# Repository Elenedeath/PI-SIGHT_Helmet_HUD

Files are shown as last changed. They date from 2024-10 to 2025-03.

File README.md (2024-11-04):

# PI-SIGHT Helmet HUD

PI-SIGHT Helmet HUD는 헬멧 외부에 장착하여 사용자의 눈앞에 필요한 정보를 표시하는 헤드 업 디스플레이 장치 입니다. 사용자는 고개를 움직이지 않고도 눈앞의 디스플레이를 통해 필요한 정보 또는 후방카메라 영상을 확인할 수 있습니다.

기기의 가장 큰 특징은 소형 범용 컴퓨터인 라즈베리 파이와 교체식 모듈 시스템을 적용했다는 것입니다. 이를 통해 사용자가 직접 소프트웨어를 프로그래밍하거나 필요한 소프트웨어로 교체할 수 있고, 블루투스 헤드셋이나 GPS 모듈을 연결해 내비게이션, 레이싱 계측기, 항공 계기판 등 다양한 용도로 사용할 수 있습니다.

## 기능

 - 프리즘 디스플레이 : 눈앞에 위치한 3000cd/m^2 디스플레이를 통해 고개를 움직이거나 별도의 기기를 거치하지 않아도 필요한 정보를 확인할 수 있음
 - 범용 시스템 : 범용 리눅스 컴퓨터인 라즈베리파이를 사용해 목적에 맞는 프로그램과 센서를 쉽게 개발하여 적용할 수 있음
 - 교체형 모듈 시스템 : 프로그램과 모듈을 쉽게 교체할 수 있도록 하여 한 대의 기기를 다양한 활동에서 사용할 수 있음
 - 무선 리모컨, 후방 카메라 등 자세한 내용은 [VUDEV 웹사이트](https://sites.google.com/vudev.net/vudevnet/about-pi-sight) 또는 [설명서](https://github.com/younsj97/PI-SIGHT_Helmet_HUD/blob/main/PI-SIGHT%20%EC%82%AC%EC%9A%A9%EC%84%A4%EB%AA%85%EC%84%9C-1%20(%EB%94%94%EB%B0%94%EC%9D%B4%EC%8A%A4%20%EA%B8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)를 다운로드하여 확인하세요

## 소프트웨어

 1. [Openauto](https://github.com/younsj97/PI-SIGHT_SW_Openauto) : 안드로이드 스마트폰과 연결해 안드로이드 오토 헤드 유닛으로 사용할 수 있습니다.
 2. [GPS Racer](https://github.com/younsj97/PI-SIGHT_SW_GPSRacer) : 자체 랩타이머 또는 스마트폰 연동 블루투스 GPS 수신기로 사용할 수 있습니다.
 3. [Rearview](https://github.com/younsj97/PI-SIGHT_SW_Rearview) : 실시간 후방 카메라 영상을 보여주며, 작동 중 자동으로 녹화됩니다.
 - 누구든지 필요한 프로그램과 모듈을 제작해 사용할 수 있습니다.

## 제작 방법

 - 업로드 예정

## 주의사항

 - _PI-SIGHT는 다양한 환경에서 충분한 테스트를 거치지 않았습니다. 제작과 사용은 자유지만, 그로 인해 발생하는 문제에 대하여 책임지지 않습니다._
 - _PI-SIGHT는 방진,방수를 지원하지 않습니다. 물이 들어가지 않도록 하세요_
 - _프리즘 디스플레이의 텐션 조절 볼트가 너무 느슨하면 사용 중 디스플레이가 움직여 위험할 수 있습니다_

## 커스터마이징

 - 무선 리모컨 펌웨어는 [PI-SIGHT Remote Controller SW](https://github.com/younsj97/PI-SIGHT_SW_RemoteController)를 참고하세요
 - PCB 회로 및 모듈 커넥터는 [회로](https://github.com/younsj97/PI-SIGHT_Helmet_HUD/blob/main/Documents/Circuits.pdf) 자료를 참고하세요

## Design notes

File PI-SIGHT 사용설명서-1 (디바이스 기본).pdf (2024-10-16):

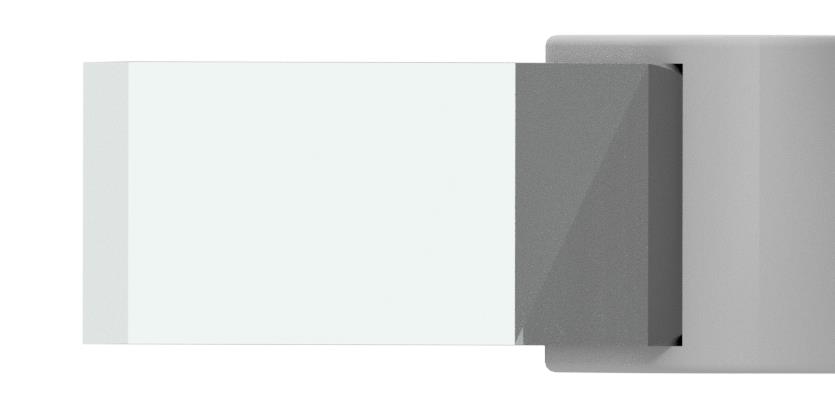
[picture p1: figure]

# PI-SIGHT 기기 사용 설명서

www.vudev.net | VUDEV | PI-SIGHT

주의사항 · · · · · · · · · · · · · · · · · · · · · · · · · · · · · · · · · · · · · · · · · · · · · · · · · · · · · · · · · · · · · · 3 1 소개/제품 구성 · · · · · · · · · · · · · · · · · · · · · · · · · · · · · · · · · · · · · · · · · · · · · · · · · · · · · · · 4 2 기술 사양 · · · · · · · · · · · · · · · · · · · · · · · · · · · · · · · · · · · · · · · · · · · · · · · · · · · · · · · · · · 5

### 3 시작하기

3.1 PI-SIGHT 부품명 · · · · · · · · · · · · · · · · · · · · · · · · · · · · · · · · · · · · · · · · · · · · · · 6 3.2 바디 세트 설치하기 · · · · · · · · · · · · · · · · · · · · · · · · · · · · · · · · · · · · · · · · · · · · · 8 3.3 리모컨 설치하기 · · · · · · · · · · · · · · · · · · · · · · · · · · · · · · · · · · · · · · · · · · · · · · · 11 3.4 배터리 및 메모리카드 넣기 · · · · · · · · · · · · · · · · · · · · · · · · · · · · · · · · · · · · · · · 12 3.5 전원 켜기 및 끄기, 충전하기 · · · · · · · · · · · · · · · · · · · · · · · · · · · · · · · · · · · · · · 13 4 소프트웨어 설치 · · · · · · · · · · · · · · · · · · · · · · · · · · · · · · · · · · · · · · · · · · · · · · · · · · · · · 19 5 문제 해결 · · · · · · · · · · · · · · · · · · · · · · · · · · · · · · · · · · · · · · · · · · · · · · · · · · · · · · · · · · 20 5.1 메인바디 작동 문제
5.2 리모컨 충전 불빛 문제
5.3 디스플레이 고정 문제
목차 | VUDEV | PI-SIGHT

다음 주의사항을 준수하십시오.

- 카메라 사용과 관련된 모든 규정을 준수하십시오.
- 카메라는 낮은 수준의 자기장이 발생합니다. 간섭을 피하기 위해 의료장비와 거리를 유지하 십시오.
- 카메라에서 발생하는 낮은 수준의 자기장은 다른 전자기기에 간섭을 일으킬 수 있습니다.
- 부주의하게 사용하면 위험하며 심각한 상해를 초래할 수 있습니다. 문서의 안전을 위한 주의 사항을 준수해야 합니다.
- 무선통신이 금지된 장소에서는 제품의 전원을 끄십시오.
- 사용 전에 제품이 올바르게 고정되었는지 다시 한번 확인하십시오. 사용 중 제품이 분리될 경 우 제품이 손상되고 사고가 발생할 수 있습니다
- 제품을 사용하거나 충전하는 중에 비정상적인 냄새가 나거나 발열 또는 다른 이상 증상이 보 인다면 즉시 충전이나 사용을 멈추십시오.
- 제품을 헬멧에 장착하는 경우 헬멧의 보증이 무효가 되거나 헬멧의 기능을 방해할 수 있습니 다. 따라서 제품을 사용하시기 전에 이로 인해 초래되는 사고 발생 시의 위험에 대해서 충분히 숙지해야 합니다.
- 제품을 사용하기 전에 해당 지역의 법률을 이해하고 해당 규정을 준수하는지 확인하십시오.
- 날카로운 공구로 제품에 충격을 가하거나, 케이블을 과도하게 잡아당기지 마십시오. 제품이 손상될 수 있습니다.
주의사항 | VUDEV | PI-SIGHT
- 애완동물이나 유아의 손이 닿지 않는 곳에 보관하십시오.
- 카메라가 정상적으로 작동하는지 사전에 확인하십시오.
- 직사광선 아래에서 장시간 사용하지 마십시오. 제품이 손상되고 발열로 화상을 입을 수 있습 니다.
- 더운 날씨에 자동차 내부에서 배터리를 장착한 제품을 사용하거나 보관하지 마십시오. 배터 리가 발열 또는 발화할 수 있습니다.
- 물리적으로 손상된 배터리를 장착하지 마십시오. 폭발이나 사고의 원인이 될 수 있습니다.
- 배터리 수명은 상황, 환경, 기능에 따라 달라질 수 있습니다.
- 제품을 상온에 보관하십시오. 극단적인 저온이나 고온에 둘 경우 기기가 손상될 수 있습니다.
- 디스플레이 보호에 유의하고, 프리즘에 이물질이 붙었을 경우 부드러운 천으로 표면을 닦으 십시오.
- 제품에 방수 기능이 없기 때문에 비나 눈이 오는 환경에서 제품을 사용하지 마십시오.
- 이 기기는 업무용(A급) 전자파적합기기로서 판매자 또는 사용자는 이 점을 주의하시기 바라 며, 가정외의 지역에서 사용하는 것을 목적으로 합니다.

PI-SIGHT를 구매해 주셔서 감사합니다.

PI-SIGHT는 헬멧 착용자의 눈앞에 필요한 정보를 표시하는 헤드 업 디스플레이(HUD) 장치 입 니다.
여러분은 눈앞의 반투명 디스플레이를 통해 고개를 움직이지 않고 필요한 정보를 확인할 수 있 고, 무선 리모컨을 통해 기기를 조작할 수 있습니다.

라즈베리 파이 제로 2W 보드와 라즈베리 파이 OS를 기반으로 작동하며, 메모리카드에 원하는 소프트웨어를 다운받아 설치하거나 직접 개발하여 사용할 수 있습니다.
또한 블루투스 헤드셋이나 GPS와 같은 외장 모듈을 연결할 수 있으므로, 필요에 따라 내비게이 션, 레이싱 계측기, 항공 계기판 등 다양한 용도로 사용할 수 있습니다.

본 설명서에서는 기본적으로 제공되는 리어뷰 소프트웨어에 대한 내용을 다룹니다. 기기에서 녹 화한 영상을 확인하기 위해서는 별도의 윈도우 PC가 필요합니다.

PI-SIGHT에 사용할 수 있는 모듈과 소프트웨어에 대한 더 많은 정보는 vudev.net 을 참고하 십시오.

1. 소개 / 제품 구성 | VUDEV | PI-SIGHT

상자에는 다음과 같은 항목이 있습니다.

- PI-SIGHT 디스플레이 유닛
- PI-SIGHT 메인바디-카메라 유닛
- PI-SIGHT 파이 마이크 유닛
- PI-SIGHT 리모컨
- 마이크로 SD 메모리 (리어뷰 소프트웨어 설치)
- 헬멧 마운트
- 마이크 부착용 벨크로
- 십자 드라이버
- 사용 설명서
*제품에는 배터리와 충전기가 포함되어 있지 않습니다. 제품을 작동시키고 충전하려면 별도로 구입해야 합니다. 자세한 내용은 기술 사양을 참조하십시오.
*제품에는 마이크로 SD 메모리를 PC에 연결할 수 있는 어댑터가 포함되어 있지 않습니다. 녹화 영상을 확인하고 소프트웨어 재설치를 위해서는 별도로 구입해야 합니다.

PI-SIGHT 바디 세트

- 길이: 메인바디 105.5mm / 카메라 21mm / 디스플레이 71mm
- 높이: 메인바디 35mm / 카메라 23.5mm / 디스플레이 47.5mm
- 너비: 메인바디 34.4mm / 카메라 35mm / 디스플레이 38mm
- 무게: 145g (배터리 포함)
- 화면 크기: 0.23인치 / 3미터 50인치
- 화면 해상도: 640*400
- 카메라: 500만 화소 120도 광각
- 비디오 해상도: 1296*860p (사용자가 변경 가능 / 최대 1920*1080p)
- 메인보드: 라즈베리파이 제로 2W
- 프로세서: 1GHz quad-core 64-bit Arm Cortex-A53 CPU
- 램 용량: 512MB
- 무선 통신: 2.4GHz 802.11 b/g/n Wi Fi , Bluetooth 4.2, BLE
- 커넥터: 충전용 USB-C, 디스플레이용 3.5mm, 파이 마이크용 3.5mm
- 메모리카드: 32GB 마이크로 SD (추가 구입 시 Class 10 이상 권장)
- *배터리: 18650 리튬이온 교체식
*배터리 별도 구입 필요
2. 기술 사양 | VUDEV | PI-SIGHT

PI-SIGHT 리모컨

- 길이: 87mm
- 높이: 87.5mm
- 너비: 23mm
- 무게: 85g (배터리 포함)
- 커넥터: 충전용 USB-C
- 무선 통신: Bluetooth 4.2
- *배터리: 18650 리튬이온 교체식
*배터리 별도 구입 필요
- 작동 시간: 메인바디 약 5시간, 리모컨 약 16시간 (3500mAh, 화면 밝기 중간 기준, 사용 소프트웨어마다 다를 수 있음)

## 3. 시작하기

– PI

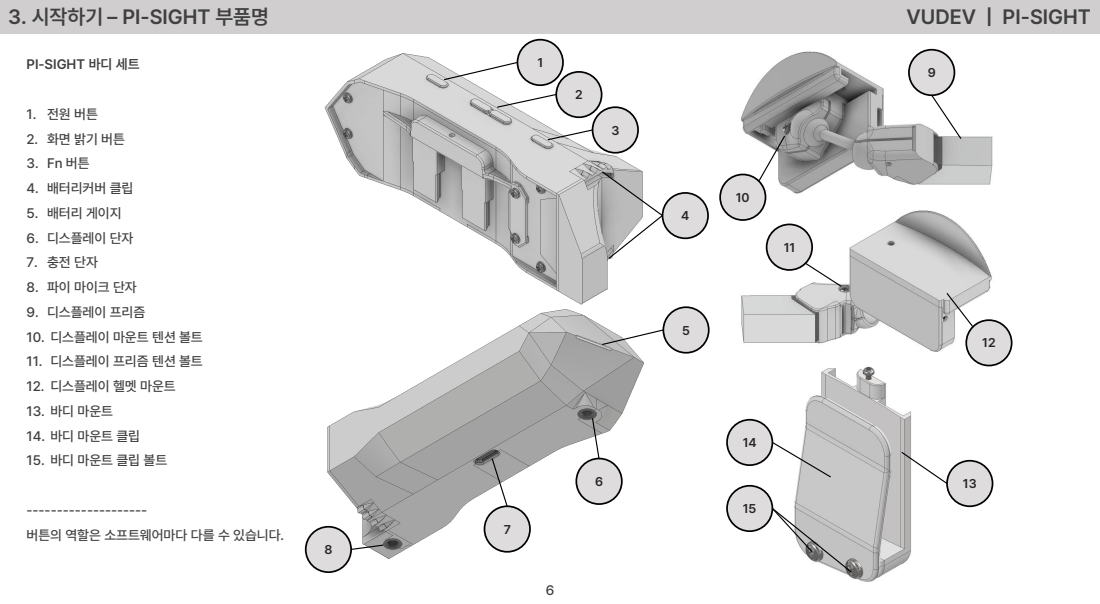
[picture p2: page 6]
수 있습니다; -SIGHT 부품명; VUDEV | PI; -SIGHT

-SIGHT 바디 세트

4. 배터리커버 클립
5. 배터리 게이지
6. 디스플레이 단자
8. 파이 마이크 단자
9. 디스플레이 프리즘
10. 디스플레이 마운트 텐션 볼트
11. 디스플레이 프리즘 텐션 볼트
12. 디스플레이 헬멧 마운트
13. 바디 마운트
14. 바디 마운트 클립
15. 바디 마운트 클립 볼트

버튼의 역할은 소프트웨어마다 다를

3. 시작하기 – PI-SIGHT 부품명 | VUDEV | PI-SIGHT

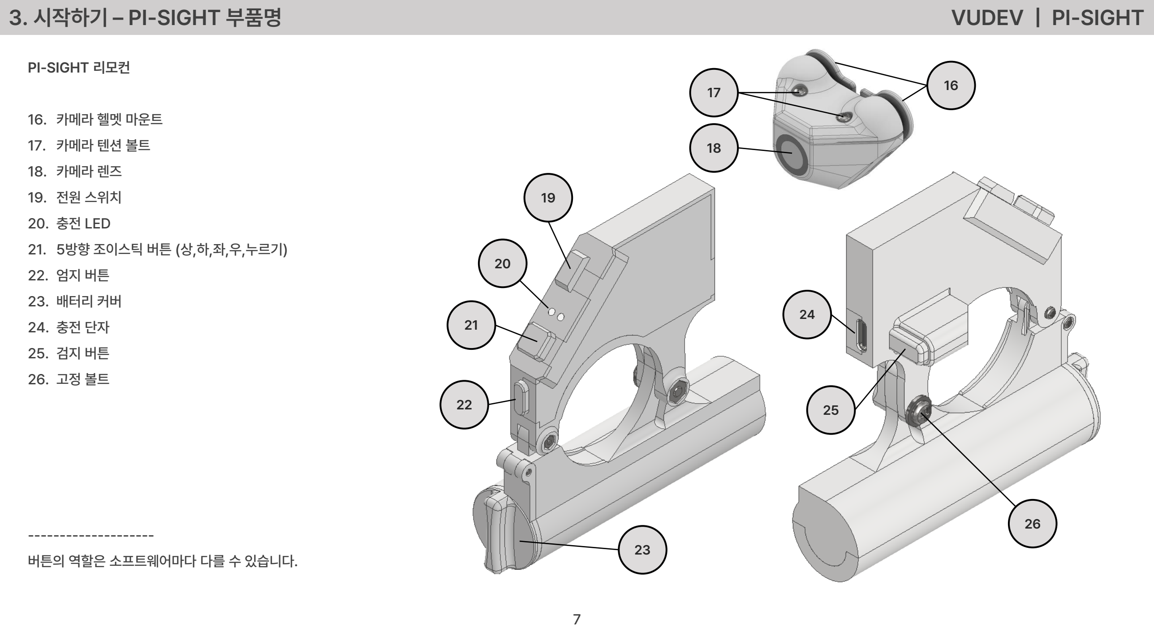
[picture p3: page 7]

PI-SIGHT 리모컨

16. 카메라 헬멧 마운트
17. 카메라 텐션 볼트
18. 카메라 렌즈
19. 전원 스위치
20. 충전 LED
21. 5방향 조이스틱 버튼 (상,하,좌,우,누르기)
22. 엄지 버튼
23. 배터리 커버
24. 충전 단자
25. 검지 버튼
26. 고정 볼트
버튼의 역할은 소프트웨어마다 다를 수 있습니다.

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
16 17

18

3. 시작하기 – 바디 세트 설치하기 | VUDEV | PI-SIGHT

1 2

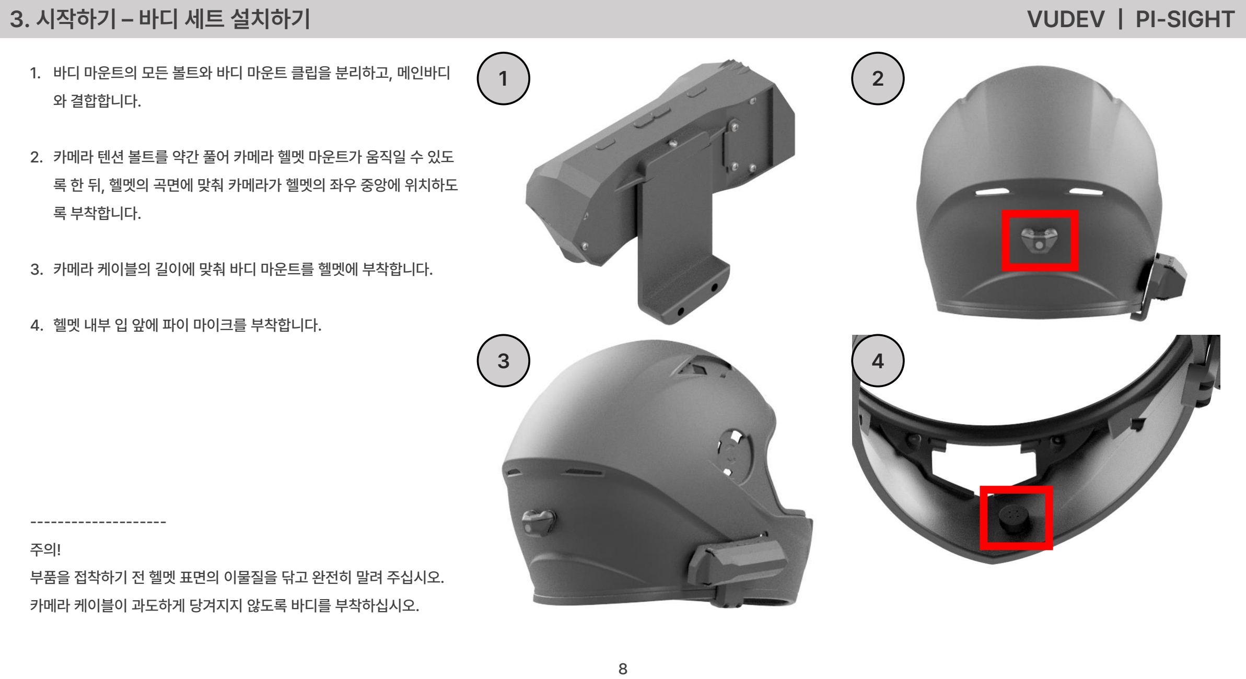
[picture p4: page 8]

1. 바디 마운트의 모든 볼트와 바디 마운트 클립을 분리하고, 메인바디 와 결합합니다.
2. 카메라 텐션 볼트를 약간 풀어 카메라 헬멧 마운트가 움직일 수 있도 록 한 뒤, 헬멧의 곡면에 맞춰 카메라가 헬멧의 좌우 중앙에 위치하도 록 부착합니다.
3. 카메라 케이블의 길이에 맞춰 바디 마운트를 헬멧에 부착합니다.
4. 헬멧 내부 입 앞에 파이 마이크를 부착합니다.
주의!
부품을 접착하기 전 헬멧 표면의 이물질을 닦고 완전히 말려 주십시오. 카메라 케이블이 과도하게 당겨지지 않도록 바디를 부착하십시오.

3 4

3. 시작하기 – 바디 세트 설치하기 | VUDEV | PI-SIGHT

5 6

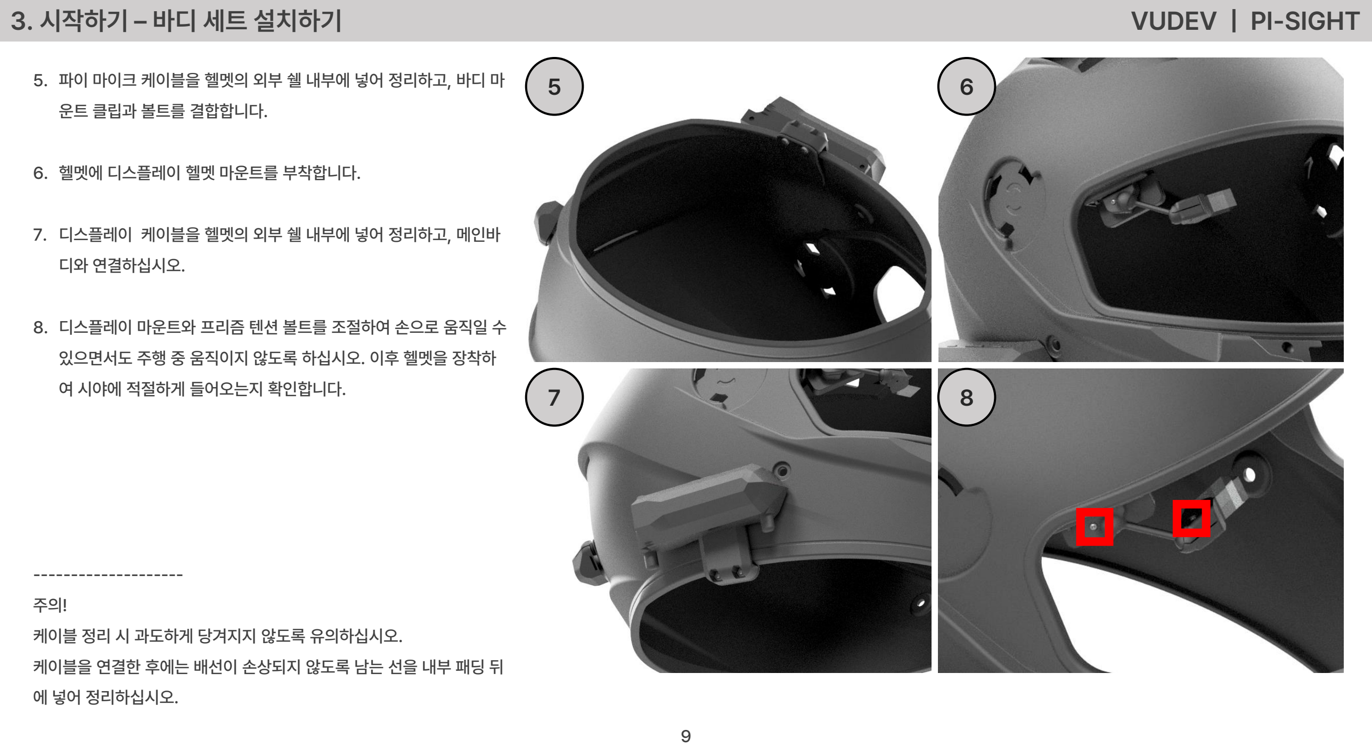
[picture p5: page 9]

7 8

5. 파이 마이크 케이블을 헬멧의 외부 쉘 내부에 넣어 정리하고, 바디 마 운트 클립과 볼트를 결합합니다.
6. 헬멧에 디스플레이 헬멧 마운트를 부착합니다.
7. 디스플레이 케이블을 헬멧의 외부 쉘 내부에 넣어 정리하고, 메인바 디와 연결하십시오.
8. 디스플레이 마운트와 프리즘 텐션 볼트를 조절하여 손으로 움직일 수 있으면서도 주행 중 움직이지 않도록 하십시오. 이후 헬멧을 장착하 여 시야에 적절하게 들어오는지 확인합니다.
주의!
케이블 정리 시 과도하게 당겨지지 않도록 유의하십시오.
케이블을 연결한 후에는 배선이 손상되지 않도록 남는 선을 내부 패딩 뒤 에 넣어 정리하십시오.

3. 시작하기 – 바디 세트 설치하기 | VUDEV | PI-SIGHT

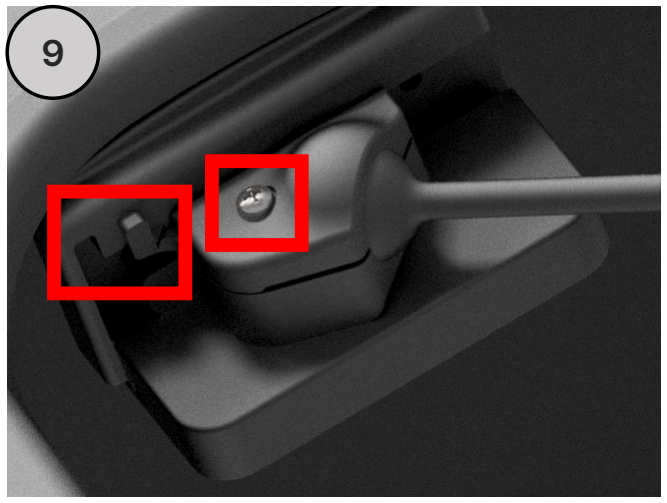
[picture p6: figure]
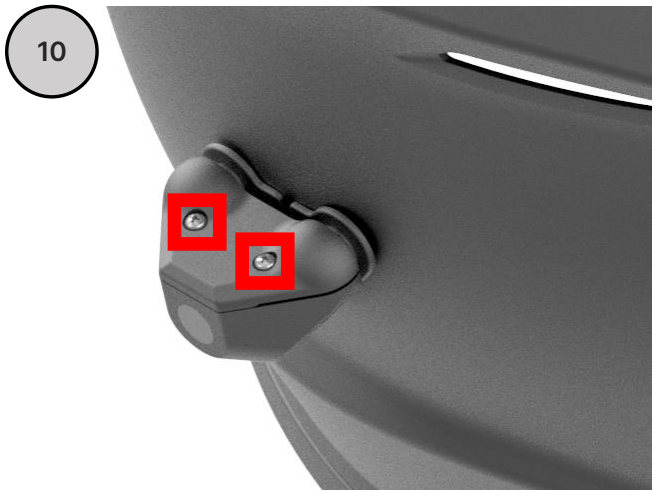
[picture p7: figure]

9 10 9. 디스플레이 마운트 텐션 볼트를 완전히 풀고 커버를 분리하면 클립을
움직여 마운트를 앞뒤로 1단계 조절할 수 있습니다.
10. 전원을 켜고 후방카메라를 확인해 카메라의 상하 각도를 조절하고,
카메라 텐션 볼트를 조여 움직이지 않도록 하십시오.

3. 시작하기 – 리모컨 설치하기 | VUDEV | PI-SIGHT

1 2

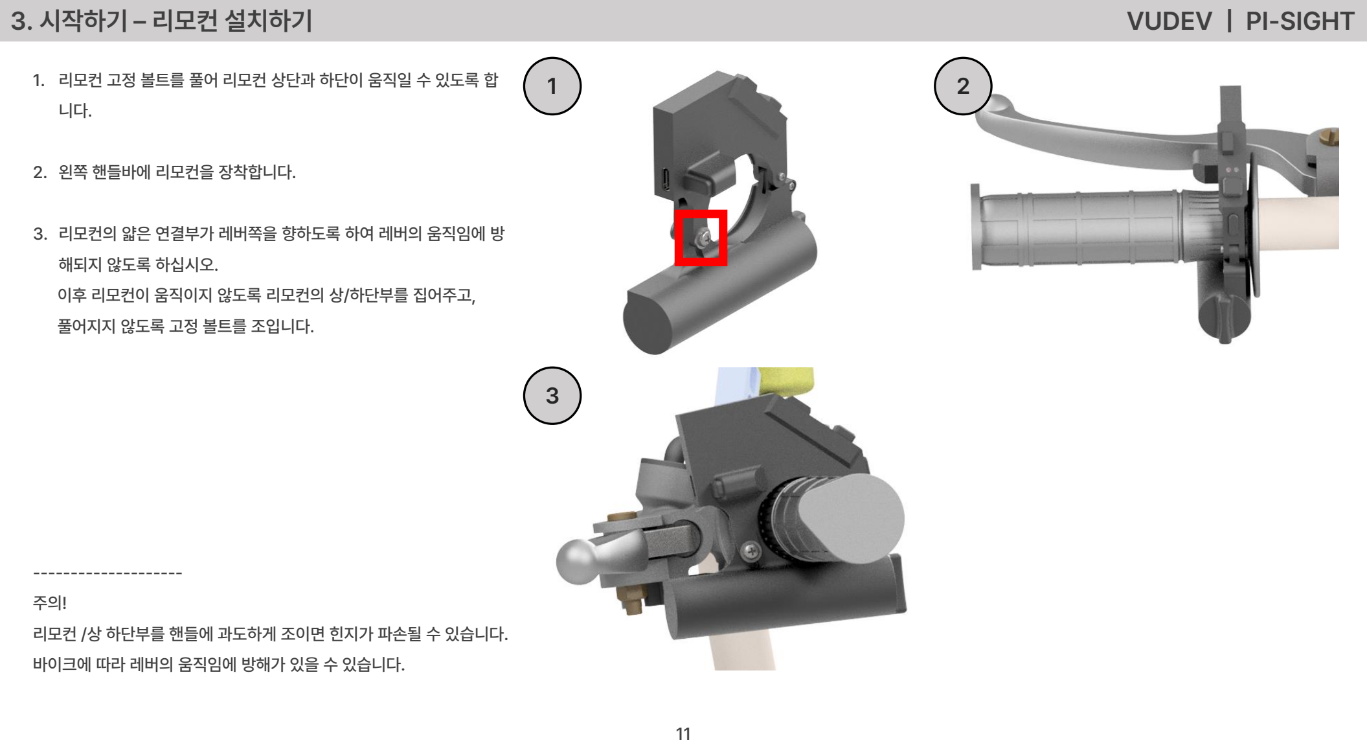
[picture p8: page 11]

3

1. 리모컨 고정 볼트를 풀어 리모컨 상단과 하단이 움직일 수 있도록 합 니다.
2. 왼쪽 핸들바에 리모컨을 장착합니다.
3. 리모컨의 얇은 연결부가 레버쪽을 향하도록 하여 레버의 움직임에 방 해되지 않도록 하십시오.
이후 리모컨이 움직이지 않도록 리모컨의 상/하단부를 집어주고, 풀어지지 않도록 고정 볼트를 조입니다.
주의!
리모컨 /상 하단부를 핸들에 과도하게 조이면 힌지가 파손될 수 있습니다. 바이크에 따라 레버의 움직임에 방해가 있을 수 있습니다.

3. 시작하기 – 배터리 및 메모리카드 넣기 | VUDEV | PI-SIGHT

1 2

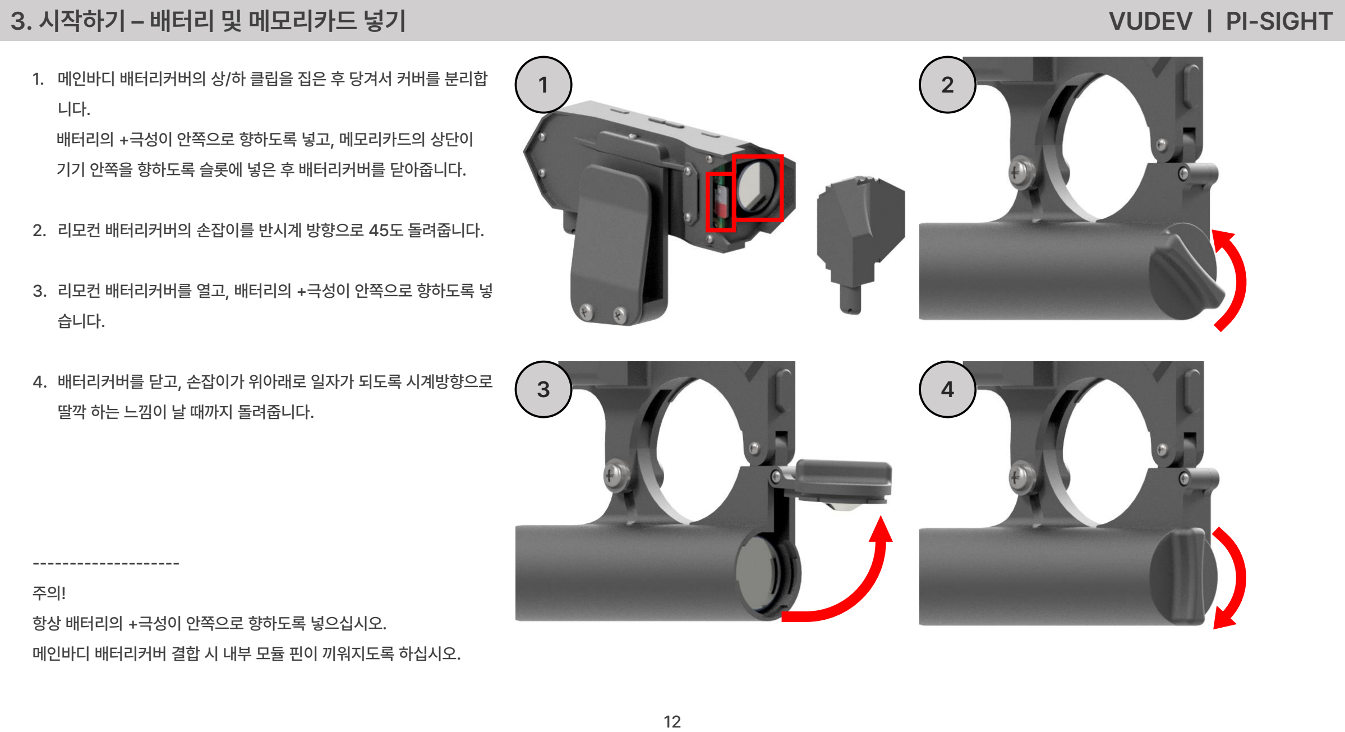
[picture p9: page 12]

3 4

1. 메인바디 배터리커버의 상/하 클립을 집은 후 당겨서 커버를 분리합 니다.
배터리의 +극성이 안쪽으로 향하도록 넣고, 메모리카드의 상단이 기기 안쪽을 향하도록 슬롯에 넣은 후 배터리커버를 닫아줍니다.
2. 리모컨 배터리커버의 손잡이를 반시계 방향으로 45도 돌려줍니다.
3. 리모컨 배터리커버를 열고, 배터리의 +극성이 안쪽으로 향하도록 넣 습니다.
4. 배터리커버를 닫고, 손잡이가 위아래로 일자가 되도록 시계방향으로 딸깍 하는 느낌이 날 때까지 돌려줍니다.
주의!
항상 배터리의 +극성이 안쪽으로 향하도록 넣으십시오.
메인바디 배터리커버 결합 시 내부 모듈 핀이 끼워지도록 하십시오.

3. 시작하기 – 전원 켜기 및 끄기,충전하기 | VUDEV | PI-SIGHT

1 2

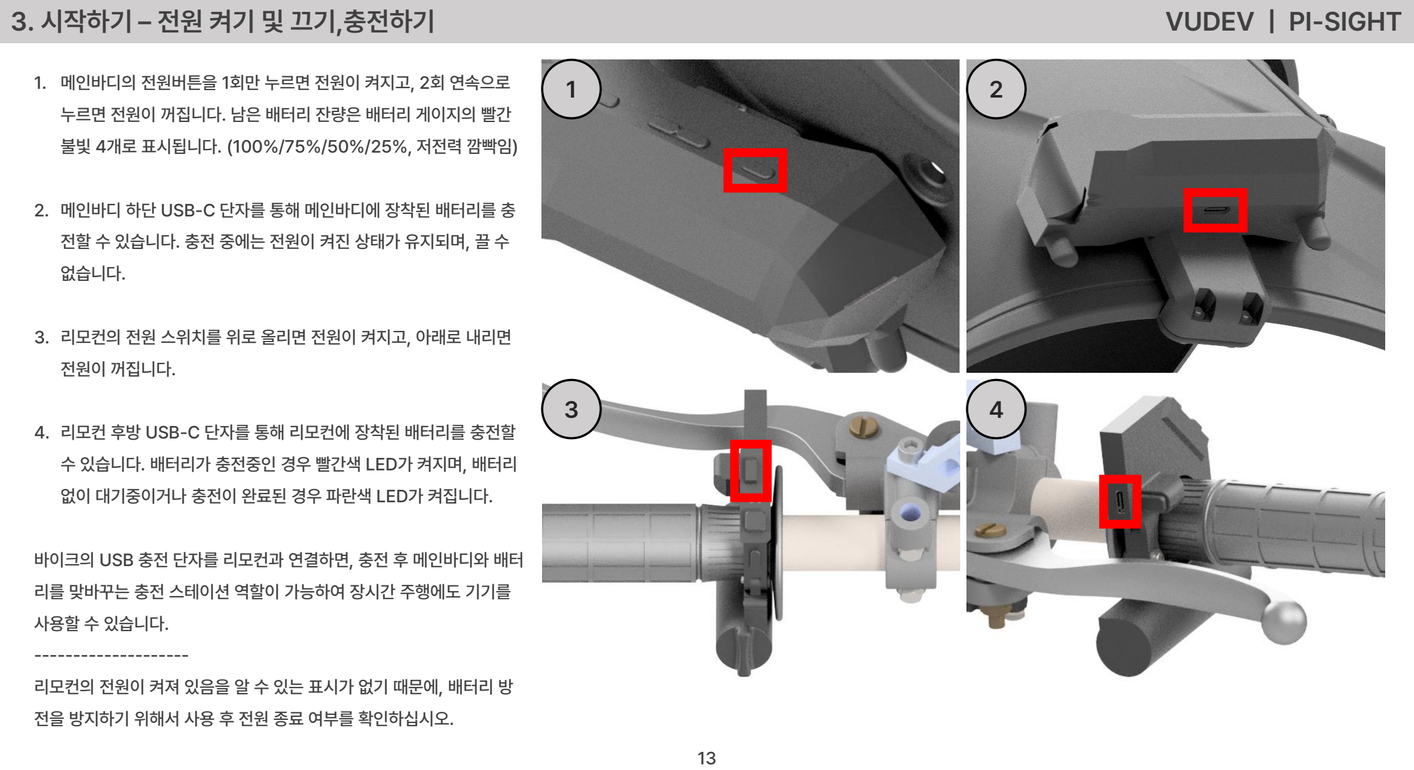
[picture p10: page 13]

3 4

1. 메인바디의 전원버튼을 1회만 누르면 전원이 켜지고, 2회 연속으로 누르면 전원이 꺼집니다. 남은 배터리 잔량은 배터리 게이지의 빨간 불빛 4개로 표시됩니다. (100%/75%/50%/25%, 저전력 깜빡임)
2. 메인바디 하단 USB-C 단자를 통해 메인바디에 장착된 배터리를 충 전할 수 있습니다. 충전 중에는 전원이 켜진 상태가 유지되며, 끌 수 없습니다.
3. 리모컨의 전원 스위치를 위로 올리면 전원이 켜지고, 아래로 내리면 전원이 꺼집니다.
4. 리모컨 후방 USB-C 단자를 통해 리모컨에 장착된 배터리를 충전할 수 있습니다. 배터리가 충전중인 경우 빨간색 LED가 켜지며, 배터리 없이 대기중이거나 충전이 완료된 경우 파란색 LED가 켜집니다.

바이크의 USB 충전 단자를 리모컨과 연결하면, 충전 후 메인바디와 배터 리를 맞바꾸는 충전 스테이션 역할이 가능하여 장시간 주행에도 기기를 사용할 수 있습니다.
리모컨의 전원이 켜져 있음을 알 수 있는 표시가 없기 때문에, 배터리 방 전을 방지하기 위해서 사용 후 전원 종료 여부를 확인하십시오.

4. 소프트웨어 설치 | VUDEV | PI-SIGHT

1 2

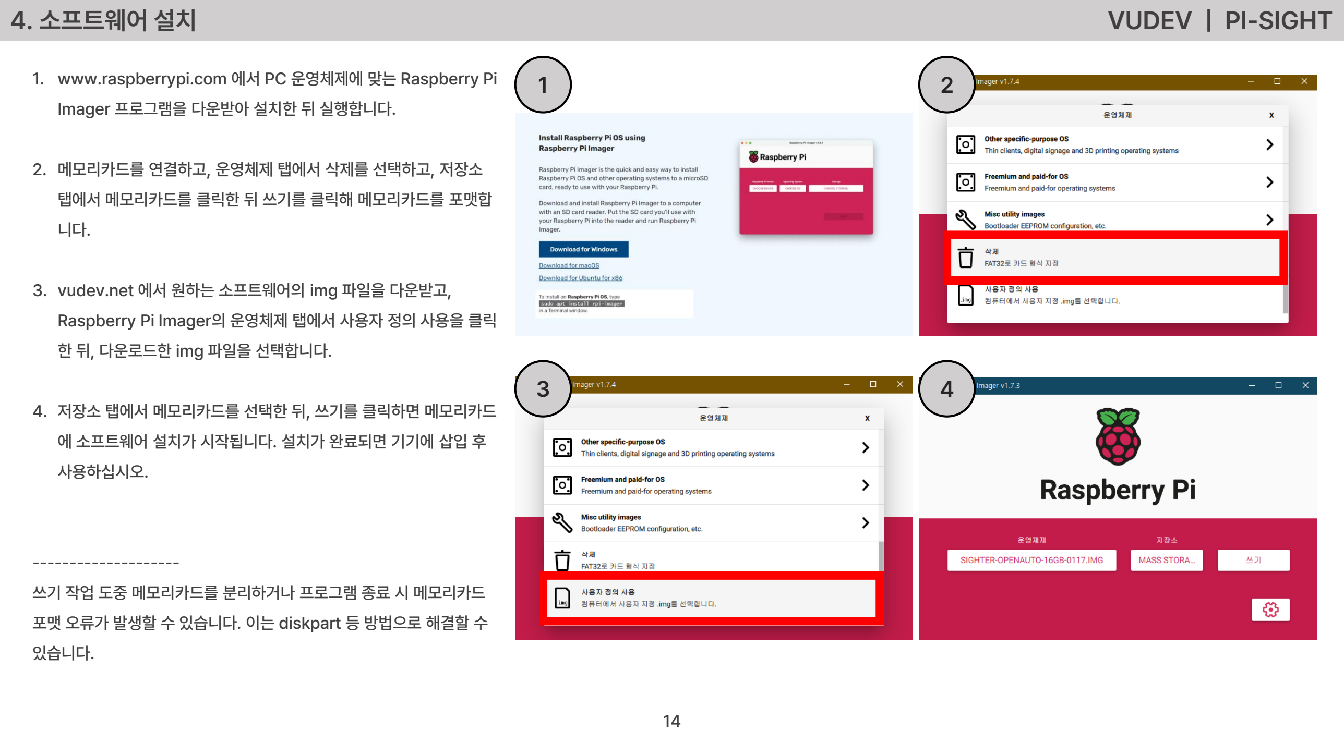
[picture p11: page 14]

3 4

1. www.raspberrypi.com 에서 PC 운영체제에 맞는 Raspberry Pi Imager 프로그램을 다운받아 설치한 뒤 실행합니다.
2. 메모리카드를 연결하고, 운영체제 탭에서 삭제를 선택하고, 저장소 탭에서 메모리카드를 클릭한 뒤 쓰기를 클릭해 메모리카드를 포맷합 니다.
3. vudev.net 에서 원하는 소프트웨어의 img 파일을 다운받고, Raspberry Pi Imager의 운영체제 탭에서 사용자 정의 사용을 클릭 한 뒤, 다운로드한 img 파일을 선택합니다.
4. 저장소 탭에서 메모리카드를 선택한 뒤, 쓰기를 클릭하면 메모리카드 에 소프트웨어 설치가 시작됩니다. 설치가 완료되면 기기에 삽입 후 사용하십시오.
쓰기 작업 도중 메모리카드를 분리하거나 프로그램 종료 시 메모리카드 포맷 오류가 발생할 수 있습니다. 이는 diskpart 등 방법으로 해결할 수 있습니다.

5.1 메인바디 작동 문제
- 배터리 게이지 불빛은 들어오지만 디스플레이가 작동하지 않을 경우, 메인바디와 디 스플레이 단자의 연결을 점검하세요.
- 배터리 게이지 불빛은 들어오지만 부팅화면이 뜨지 않는 경우, 메모리카드가 정상적 으로 삽입되었는지 확인하십시오.
- 배터리 게이지 불빛이 들어오지 않는 경우, 배터리가 정상적으로 삽입되었는지 확인 하십시오.
- 지속적으로 영상의 저장/삭제가 반복되며 일정 시간이 지나면 메모리카드의 수명이 다해 기기가 제대로 작동하지 않을 수 있습니다. 이 경우 메모리카드를 교체하고 소프 트웨어를 새로 설치하십시오.
5.2 리모컨 충전 불빛 문제
- 리모컨의 전원이 켜진 상태에서 배터리 완충 시 빨간불과 파란불이 동시에 켜지거나, 번갈아 켜지는 현상이 발생할 수 있으나, 정상작동입니다.
5.3 디스플레이 고정 문제
- 디스플레이가 단단히 고정되지 않고 쉽게 움직이는 경우, 디스플레이 마운트와 프리 즘의 텐션 볼트를 조절하여 고정 세기를 조절하십시오.
5. 문제 해결 | VUDEV | PI-SIGHT

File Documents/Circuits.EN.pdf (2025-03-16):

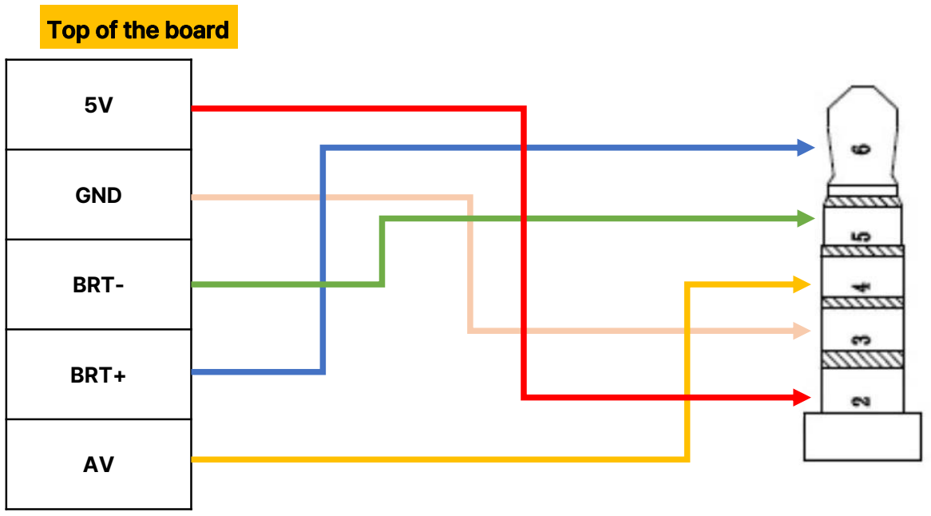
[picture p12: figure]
GND; BRT-; BRT+; Top of the board

# Display Board – 3.5mm 5pin AUX

Cable length: 45cm

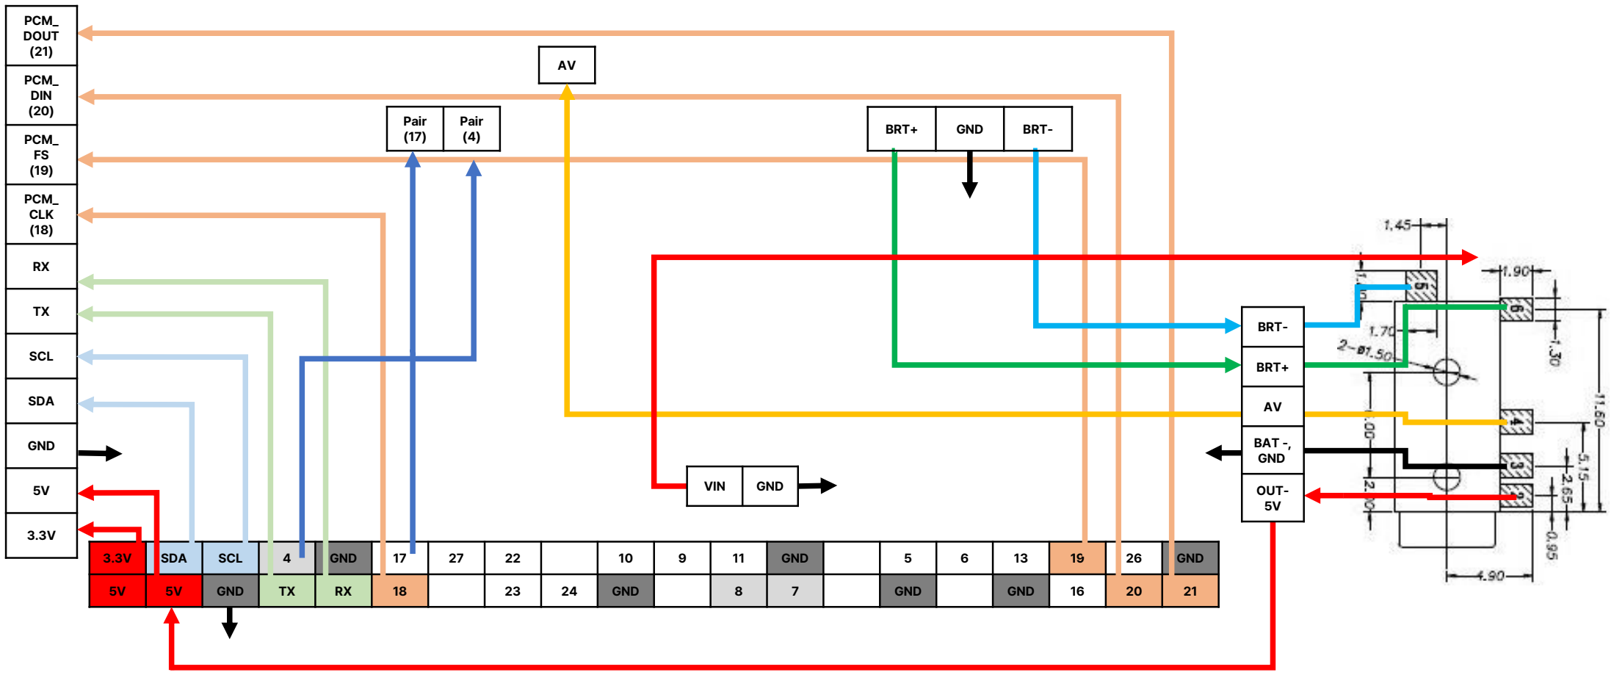
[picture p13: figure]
SDA; SCL; GND; PCM_ DOUT (21); PCM_ DIN (20); PCM_ FS (19); PCM_ CLK (18); Pair (17); Pair (4); BRT-; BRT+; BAT -, GND; OUT- 5V; VIN

# Main Body PCB - Raspberry pi

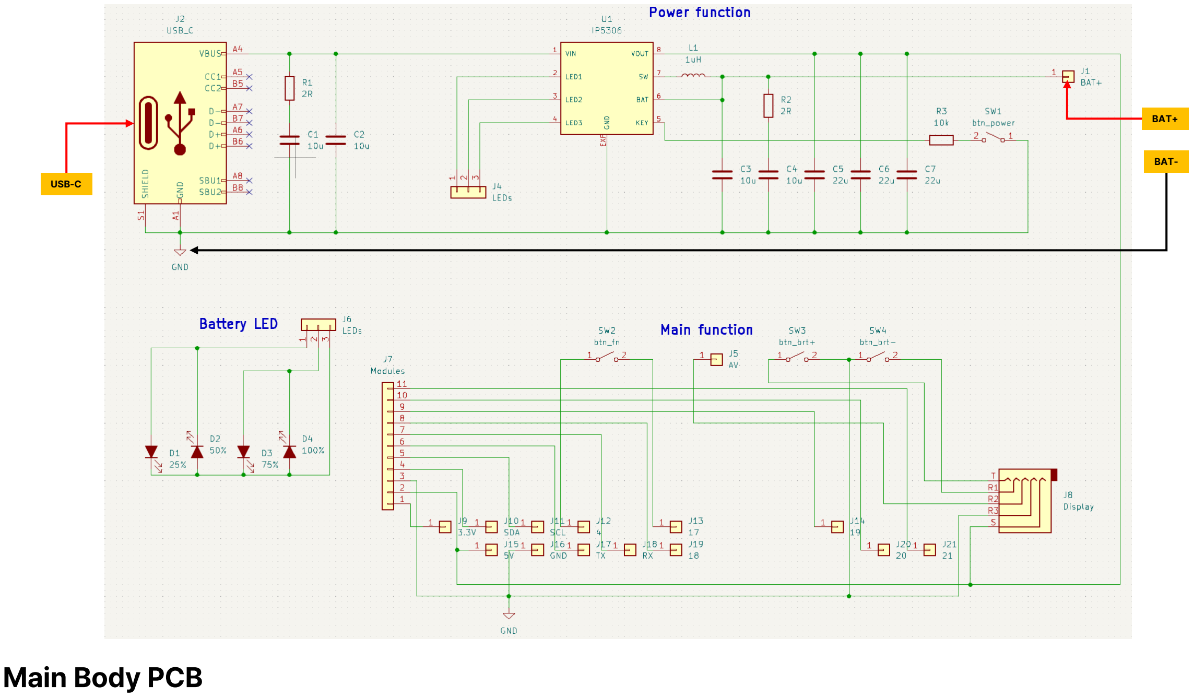
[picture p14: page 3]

# Main Body PCB

USB-C

BAT-

BAT+

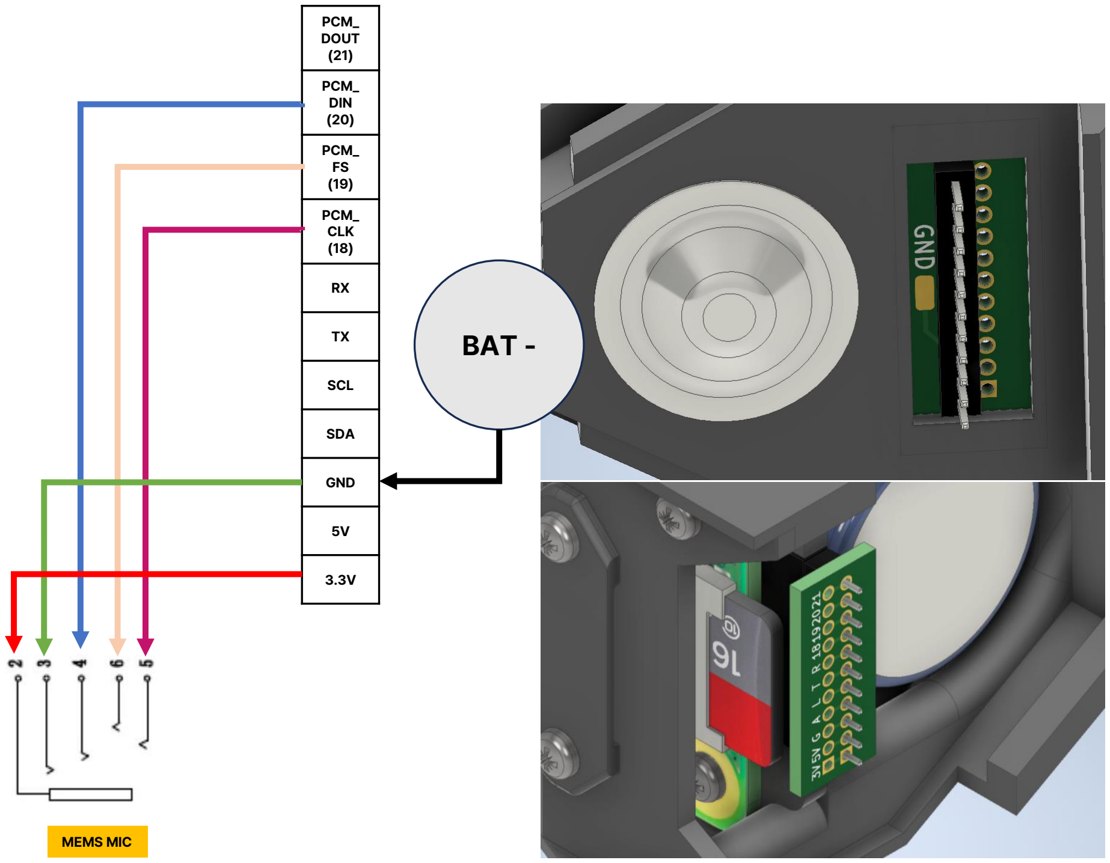
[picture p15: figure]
PCM_ DOUT (21); PCM_ DIN (20); PCM_ FS (19); PCM_ CLK (18); SCL; SDA; GND; BAT -; MEMS MIC
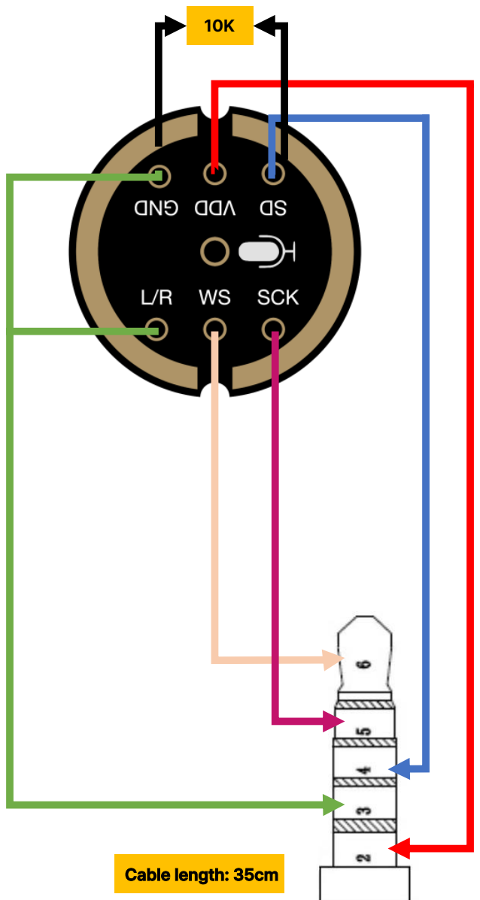
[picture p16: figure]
Cable length: 35cm
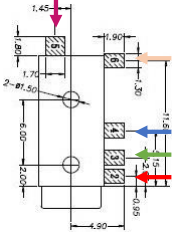
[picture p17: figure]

# MEMS Mic, Battery Cover (Basic Module)

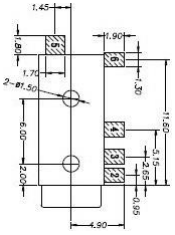
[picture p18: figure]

# BT Audio Module

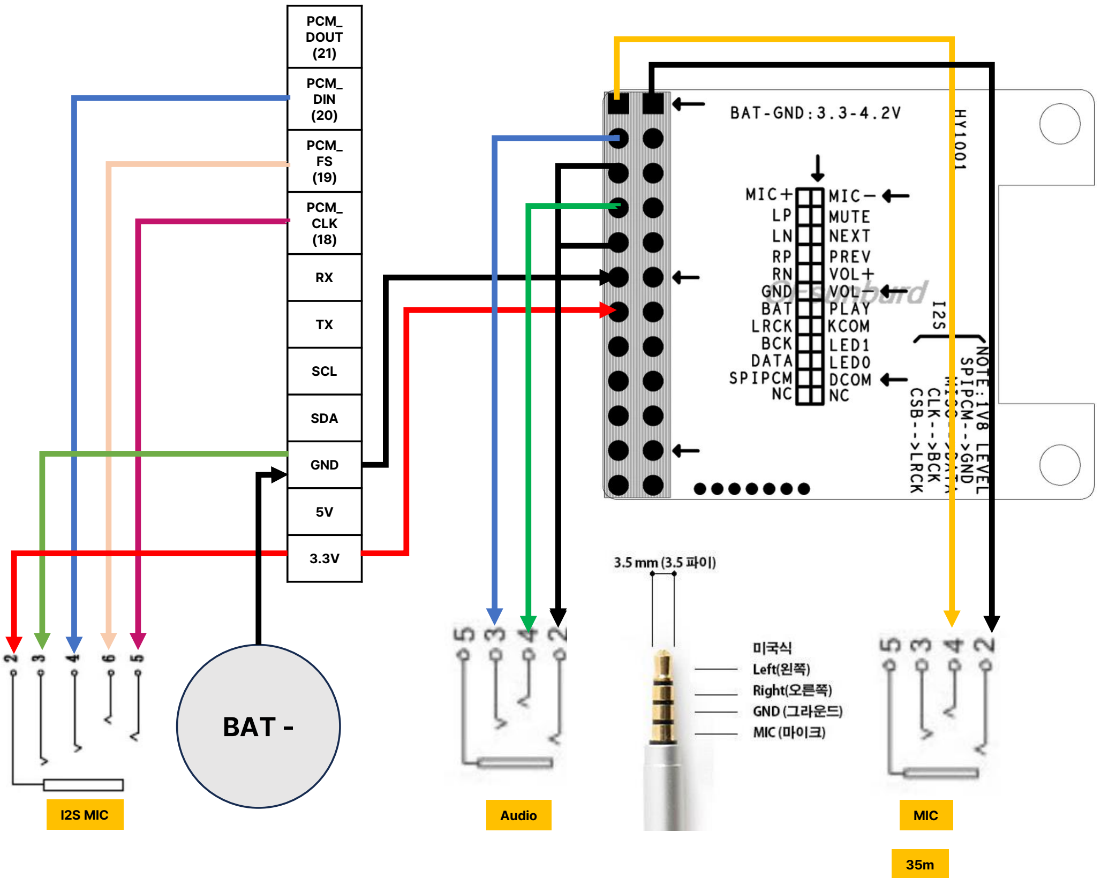
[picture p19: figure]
PCM_ DOUT (21); PCM_ DIN (20); PCM_ FS (19); PCM_ CLK (18); SCL; SDA; GND; BAT -; I2S MIC; Audio; MIC
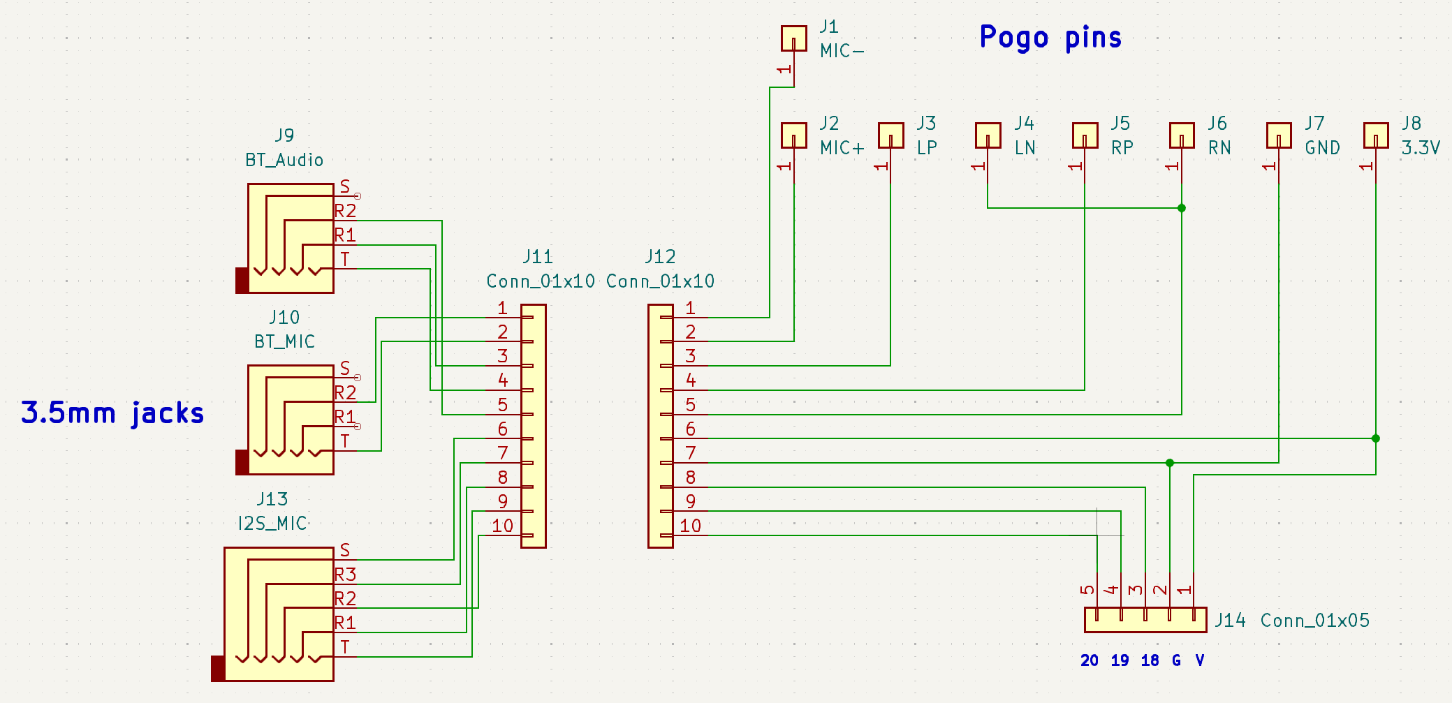
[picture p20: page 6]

# BT Audio Module PCB

# GPS Module

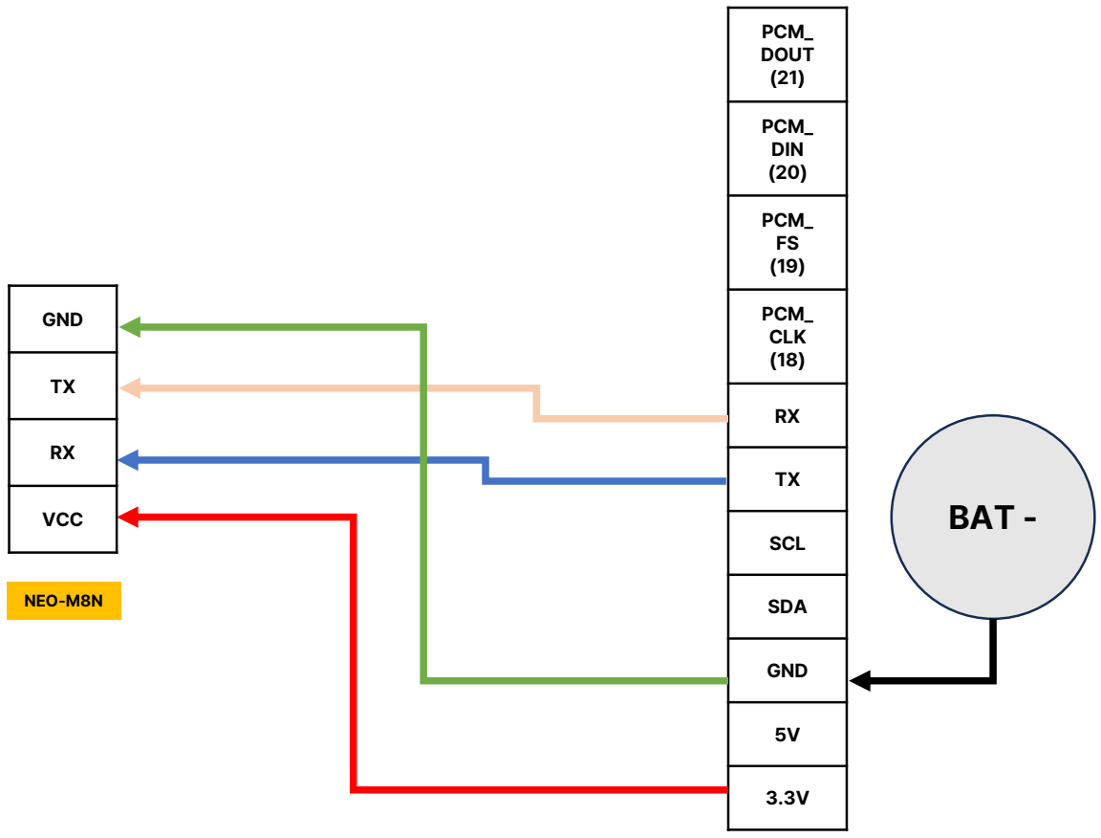
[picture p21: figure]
PCM_ DOUT (21); PCM_ DIN (20); PCM_ FS (19); PCM_ CLK (18); SCL; SDA; GND; BAT; VCC; NEO
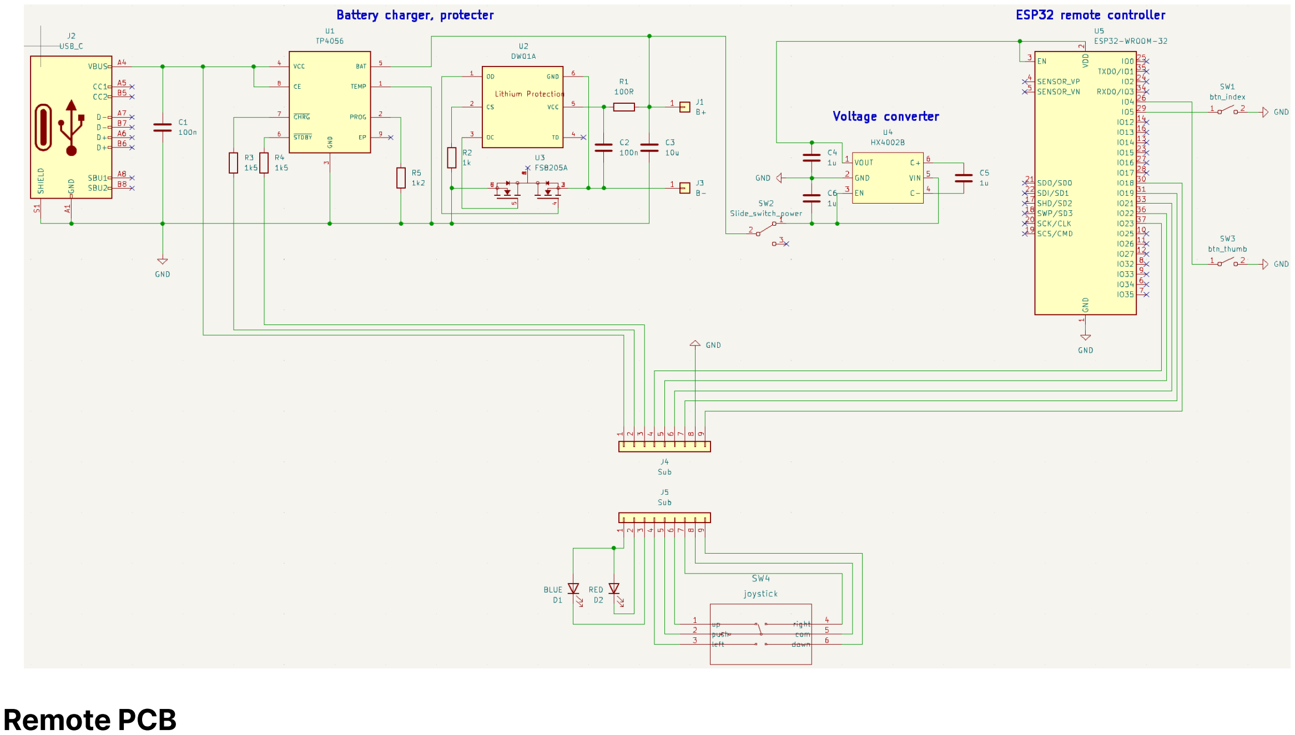
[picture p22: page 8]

# Remote PCB

USB-C

BAT

HX4002B

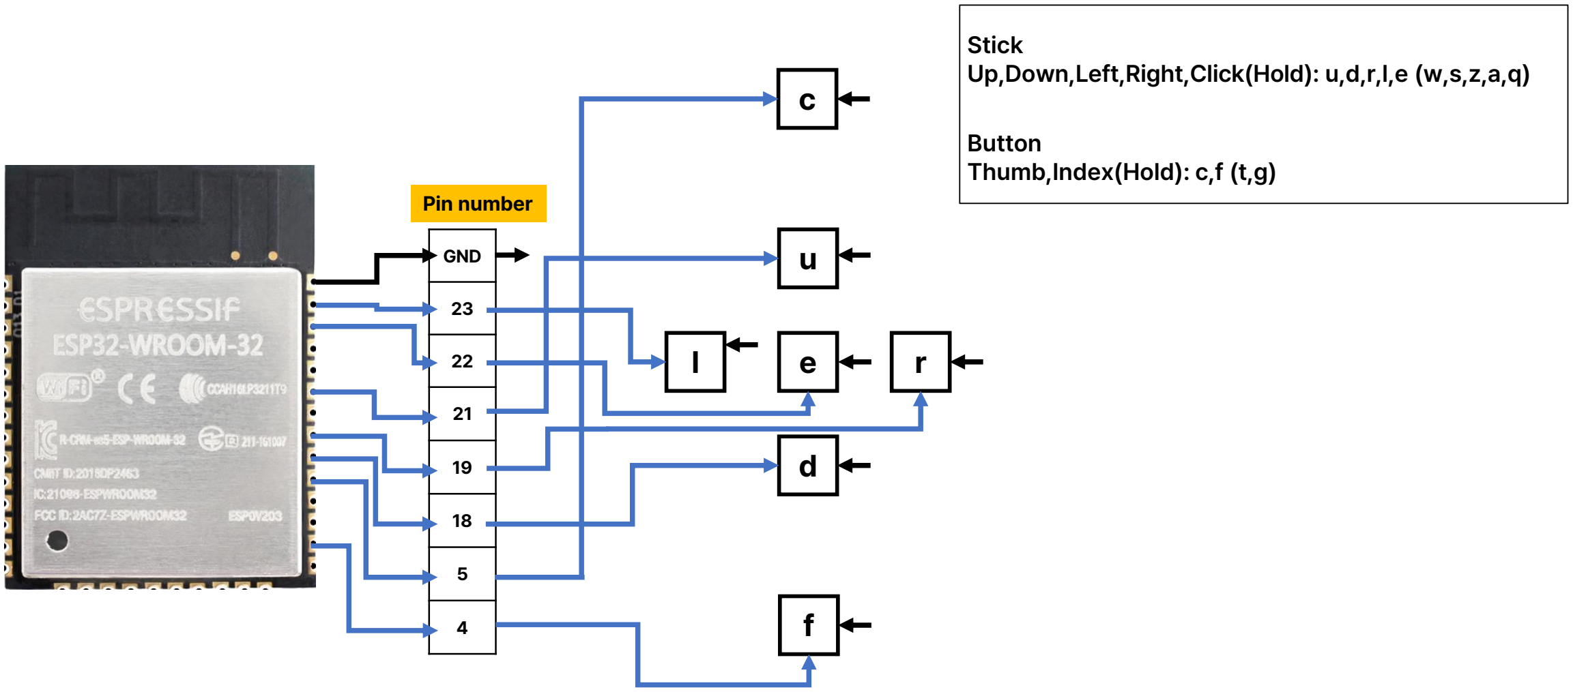
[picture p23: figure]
GND; Pin number; Stick; Button Thumb,Index(Hold): c,f (t,g)

# Remote Keymap

# Up,Down,Left,Right,Click(Hold): u,d,r,l,e (w,s,z,a,q)

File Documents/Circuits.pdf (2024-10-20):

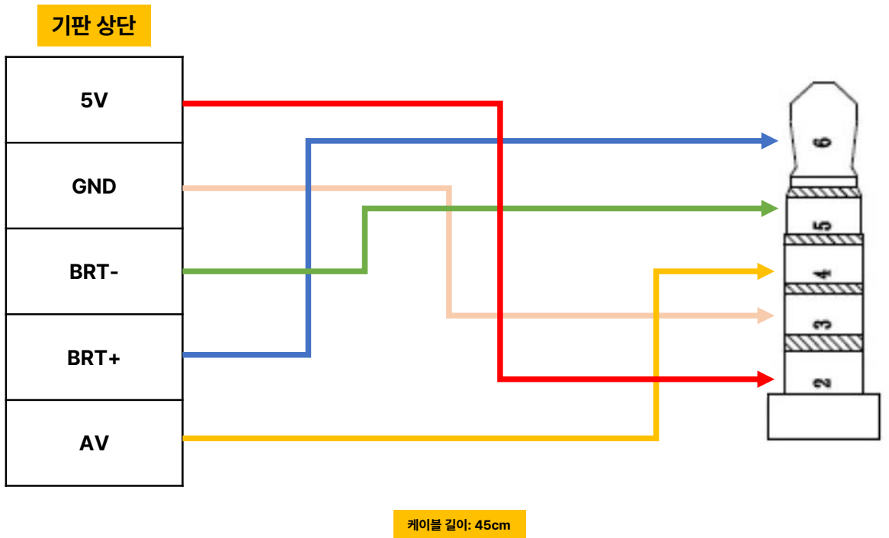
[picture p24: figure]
GND; BRT-; BRT+; 케이블 길이: 45cm

# Display Board – 3.5mm 5pin AUX

SDA; SCL; GND; PCM_ DOUT (21); PCM_ DIN (20); PCM_ FS (19); PCM_ CLK (18); Pair (17); Pair (4); BRT-; BRT+; BAT -, GND; OUT- 5V; VIN

# Main Body PCB - Raspberry pi


# Main Body PCB

USB-C

BAT-

BAT+

PCM_ DOUT (21); PCM_ DIN (20); PCM_ FS (19); PCM_ CLK (18); SCL; SDA; GND; BAT -; MEMS MIC
케이블 길이: 35cm

# MEMS Mic, Battery Cover (Basic Module)


# BT Audio Module

PCM_ DOUT (21); PCM_ DIN (20); PCM_ FS (19); PCM_ CLK (18); SCL; SDA; GND; BAT -; I2S MIC; Audio; MIC

# BT Audio Module PCB

# GPS Module

PCM_ DOUT (21); PCM_ DIN (20); PCM_ FS (19); PCM_ CLK (18); SCL; SDA; GND; BAT; VCC; NEO

# Remote PCB

USB-C

BAT

HX4002B

GND; Pin number; 버튼 엄지,검지(길게 누르기): c,f (t,g)

# Remote Keymap

# 상,하,좌,우,클릭(길게 유지): u,d,r,l,e (w,s,z,a,q)

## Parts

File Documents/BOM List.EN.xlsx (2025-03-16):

BOM | Main part |  |  |  | BOM | Module Parts |  |  |  | BOM | Other equipment
No | Module name | Product name | quantity | note | No | Module name | Product name | quantity | note | No | Equipment Classification | Product name | quantity | note
 | entity | Raspberry Pi Zero 2 W | 1 |  |  | BT Audio Module | QCC3005D BT Audio Module | 1 | Ali Link - QCC3005D (https://ko.aliexpress.com/item/1005004396553509.html?gatewayAdapt=glo2kor) |  | Soldering | Mini hot plate |  | Ali Link (https://ko.aliexpress.com/item/1005005447833330.html?gatewayAdapt=glo2kor)
 |  | Micro SD 16GB or 32GB | 1 |  |  |  | 3.5mm 5-pole socket | 1 | _ |  |  | PD 65W Charger |  | Ali Link (https://ko.aliexpress.com/item/1005005727390239.html?gatewayAdapt=glo2kor)
 |  | 18650 battery | 1 |  |  |  | 3.5mm 4 pole socket | 2 | Ali Link - PJ-320A (https://ko.aliexpress.com/item/32869968774.html?gatewayAdapt=glo2kor) |  |  | soldering paste |  | 183 Degree
 |  | Body Main Board | 1 | PI-SIGHT PCB |  |  | Pogo pin 3mm |  | _ |  |  | Soldering iron
 |  | MH-CD42 5V 2A Power Board | 1 | Ali Link (https://ko.aliexpress.com/item/32932416873.html?gatewayAdapt=glo2kor) |  |  | M3 bolt 8mm (BT module) | 2 | Ali Link - 8mm (https://ko.aliexpress.com/item/1005006276889797.html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) |  | former | Tester
 |  | 0805 SMD Capacitor 22uF | 3 | Ali Link (https://ko.aliexpress.com/item/32964553793.html) |  |  | M3 nut | 2 | _ |  | splice | Instant adhesive
 |  | 0805 SMD Capacitor 10uF | 4 | _ |  |  | M2 bolt 3mm | 2 | _ |  |  | Adhesive
 |  | 0805 SMD Resistor 2R | 2 | _ |  |  | Body module pin board | 1 | PI-SIGHT PCB |  |  | 3M Foam Double Sided Tape
 |  | 0805 SMD resistor 10k | 1 | _ |  |  | 1.27mm 11 pin straight header pin | 1 | _ |  | Programming | ESP WROOM 32 Downloader | 1 | Ali Link - ESP WROOM 32 (https://ko.aliexpress.com/item/1005005850152605.html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)
 |  | Tact switch | 4 | NW3-A06-B6 |  |  | Spring D5mm * L10mm | 1 |  |  |  | UART-USB Converter (for GPS) | 1 | Ali Link - CP2102 BLACK (https://ko.aliexpress.com/item/1005005850315101.html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)
 |  | Pogo pin 3mm | 14 | Ali Link (https://ko.aliexpress.com/item/4001011194275.html?gatewayAdapt=glo2kor) |  |  | 30 AWG Silicone Cable (Red) | 1 | _
 |  | 3.5mm 5-pole socket | 2 | Ali Link (https://ko.aliexpress.com/item/32749792104.html?gatewayAdapt=glo2kor) |  |  | 30 AWG Silicone Cable (Black) | 1 | _
 |  | USB-C terminal SMD | 1 | link (https://www.devicemart.co.kr/goods/view?no=15088068) |  |  | 30 AWG Silicone Cable (Yellow) | 1 | _
 |  | 18650 Battery Terminals - (Spring) | 1 | Ali Link (https://ko.aliexpress.com/item/1005001268395173.html?gatewayAdapt=glo2kor) |  |  | 30 AWG Silicone Cable (Blue) | 1 | _
 |  | 18650 battery terminal + | 1 | _ |  |  | 30 AWG Silicone Cable (Orange) | 1 | _
 |  | 1.27mm 11pin bendable header socket | 1 | link (https://www.icbanq.com/P005659127) |  | speaker | Helmet speaker module | 1 | Ali Link (https://ko.aliexpress.com/item/1005003490852851.html?gatewayAdapt=glo2kor)
 |  | Body module pin board | 1 | PI-SIGHT PCB |  | Call Microphone | Condenser microphone | 1 | Ali Link (https://ko.aliexpress.com/item/32691068980.html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)
 |  | 1.27mm 11 pin straight header pin | 1 | link (https://www.icbanq.com/P005609783) |  |  | 2-wire enamel cable (power) | 1 | _
 |  | Spring D5mm * L10mm | 1 |  |  |  | 3.5mm 4-pole jack | 1 | Ali Link - 14mm 4P (https://ko.aliexpress.com/item/32966592930.html?gatewayAdapt=glo2kor)
 |  | M2 bolt 4mm (camera cable cover) | 2 | Ali Link – H Set (https://ko.aliexpress.com/item/4000011789077.html?gatewayAdapt=glo2kor) |  | GPS module | NEO-M8N GPS module | 1 | Ali Link - M8N (https://ko.aliexpress.com/item/1005002579586721.html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)
 |  | M2 bolt 8mm (pie, inner cover, mount) | 9 | _ |  |  | Body module pin board | 1 | PI-SIGHT PCB
 |  | LED board | 1 | PI-SIGHT PCB |  |  | 1.27mm 11 pin straight header pin | 1 | _
 |  | 1202 SMD LED (Red) | 4 | Extract the power board |  |  | Spring D5mm * L10mm | 1 | _
 |  | 30 AWG Silicone Cable (Red) | 2 | Ali Link (https://ko.aliexpress.com/item/1005001590476043.html?gatewayAdapt=glo2kor) |  |  | 30 AWG Silicone Cable (Red) | 1 | _
 |  | 30 AWG Silicone Cable (Black) | 2 | _ |  |  | 30 AWG Silicone Cable (Black) | 1 | _
 |  | 30 AWG Silicone Cable (Yellow) | 1 | _ |  |  | 30 AWG Silicone Cable (Yellow) | 1 | _
 |  | 30 AWG Silicone Cable (Blue) | 1 | _ |  |  | 30 AWG Silicone Cable (Blue) | 1 | _
 |  | 30 AWG Silicone Cable (Orange) | 1 | _ |  | Module Pin Converter | 1.27mm-2.54mm pin converter board | 1 | PI-SIGHT PCB
 | display | Prism Display + AV Control Board Direct Purchase via Sales Email | 1 | OL23C + AV Board (https://www.sz-sonicom.com/productinfo/689881.html) |  |  | 1.27mm 11pin header socket | 1 | link (https://www.icbanq.com/P005659127)
 |  | 5 wire enamel cable | 1 | Ali Link - 5core (https://ko.aliexpress.com/item/1005002604413691.html?gatewayAdapt=glo2kor) |  |  | 2.54mm 11pin header socket | 1 | link (https://www.icbanq.com/P005652460)
 |  | 3.5mm 5-pole jack | 1 | _
 |  | M2 bolt 6mm (top ball tensioner) | 1 | _
 |  | M2 bolt 10mm (bottom ball tensioner) | 1 | _
 | Rear camera | Camera (120 degrees, 30cm cable) | 1 | Ali Link - 120 Degree (https://ko.aliexpress.com/item/1005003637612356.html?gatewayAdapt=glo2kor)
 |  | M2 bolt 10mm | 2 | _
 | System Microphone | INMP441 MEMS MIC | 1 | Ali Link (https://ko.aliexpress.com/item/1005005933408624.html?scm_id=1007.40050.354490.0&scm-url=1007.40050.354490.0)
 |  | 0805 SMD resistor 10k | 1 | _
 |  | 5 wire enamel cable | 1 | _
 |  | 3.5mm 5-pole jack | 1 | _
 | wireless remote control | ESP WROOM 32 | 1 | Ali Link (https://ko.aliexpress.com/item/32899182878.html?gatewayAdapt=glo2kor)
 |  | Remote control main board | 1 | PI-SIGHT PCB
 |  | remote control joystick board | 1 | PI-SIGHT PCB
 |  | Slide switch | 1 | SK-12D02
 |  | Tact switch | 2 | NW3-A06-B6
 |  | Joystick | 1 | SMD070706
 |  | TP4056 USB-C 5V Power Board | 1 | Ali Link - 18650 Type-C (https://ko.aliexpress.com/item/1005006310424899.html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)
 |  | USB-C terminal SMD |  | Extract the power board
 |  | 1202 SMD LED (Red) | 1 | Extract the power board
 |  | 1202 SMD LED (Blue) | 1 | Extract the power board
 |  | 0805 SMD Capacitor 10uF | 1 | _
 |  | 0805 SMD Capacitor 100nF | 2 | _
 |  | 0805 SMD resistor 1k5 | 2 | _
 |  | 0805 SMD resistor 1k2 | 1 | _
 |  | 0805 SMD resistor 1k | 1 | _
 |  | HX4002B 3.3V Power Board | 1 | Ali Link (https://ko.aliexpress.com/item/1005004680099594.html?gatewayAdapt=glo2kor)
 |  | 18650 Battery Terminals - (Spring) | 2 | _
 |  | 2-wire enamel cable (power) | 1 | Ali Link - 2core (https://ko.aliexpress.com/item/1005002604413691.html)
 |  | Spring D5mm * L10mm | 1
 |  | M3 bolt 12mm | 1 | Ali Link - 12mm (https://ko.aliexpress.com/item/1005005742172855.html?scm_id=1007.40050.354490.0&scm-url=1007.40050.354490.0)
 |  | M3 washer | 1 | _
 |  | M3 nut | 1 | _
 |  | M2 bolt 4mm (remote control pcb) | 2 | _
 |  | M2 bolt 10mm (remote hinge) | 1 | _
 |  | M2 bolt 8mm (battery cover hinge) | 1 | _
 |  | M2 nut | 1 | Ali Link - M2 (https://ko.aliexpress.com/item/1005004833515587.html)

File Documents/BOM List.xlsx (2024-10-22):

BOM | 메인파츠 |  |  |  | BOM | 모듈파츠 |  |  |  | BOM | 기타 장비
No | 모듈명 | 품명 | 수량 | 비고 | No | 모듈명 | 품명 | 수량 | 비고 | No | 장비 분류 | 품명 | 수량 | 비고
 | 본체 | 라즈베리 파이 제로 2 W | 1 |  |  | BT 오디오 모듈 | QCC3005D BT 오디오 모듈 | 1 | 알리 링크 - QCC3005D (https://ko.aliexpress.com/item/1005004396553509.html?gatewayAdapt=glo2kor) |  | 납땜 | 미니 핫플레이트 |  | 알리 링크 (https://ko.aliexpress.com/item/1005005447833330.html?gatewayAdapt=glo2kor)
 |  | Micro SD 16GB or 32GB | 1 |  |  |  | 3.5mm 5극 소켓 | 1 | _ |  |  | PD 65W 충전기 |  | 알리 링크 (https://ko.aliexpress.com/item/1005005727390239.html?gatewayAdapt=glo2kor)
 |  | 18650 배터리 | 1 |  |  |  | 3.5mm 4극 소켓 | 2 | 알리 링크 - PJ-320A (https://ko.aliexpress.com/item/32869968774.html?gatewayAdapt=glo2kor) |  |  | 솔더링 페이스트 |  | 183 Degree
 |  | 바디 메인보드 | 1 | PI-SIGHT PCB |  |  | 포고핀 3mm |  | _ |  |  | 인두기
 |  | MH-CD42 5V 2A 전원보드 | 1 | 알리 링크 (https://ko.aliexpress.com/item/32932416873.html?gatewayAdapt=glo2kor) |  |  | M3 볼트 8mm (BT모듈) | 2 | 알리 링크 - 8mm (https://ko.aliexpress.com/item/1005006276889797.html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) |  | 전자 | 테스터
 |  | 0805 SMD 캐패시터 22uF | 3 | 알리 링크 (https://ko.aliexpress.com/item/32964553793.html) |  |  | M3 너트 | 2 | _ |  | 접착 | 순간접착제
 |  | 0805 SMD 캐패시터 10uF | 4 | _ |  |  | M2 볼트 3mm | 2 | _ |  |  | 접착제
 |  | 0805 SMD 저항 2R | 2 | _ |  |  | 바디 모듈 핀 보드 | 1 | PI-SIGHT PCB |  |  | 3M 폼 양면테이프
 |  | 0805 SMD 저항 10k | 1 | _ |  |  | 1.27mm 11핀 직선 헤더 핀 | 1 | _ |  | 프로그래밍 | ESP WROOM 32 다운로더 | 1 | 알리 링크 - ESP WROOM 32 (https://ko.aliexpress.com/item/1005005850152605.html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)
 |  | 택트 스위치 | 4 | NW3-A06-B6 |  |  | 스프링 D5mm * L10mm | 1 |  |  |  | UART-USB 컨버터 (GPS용) | 1 | 알리 링크 - CP2102 BLACK (https://ko.aliexpress.com/item/1005005850315101.html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)
 |  | 포고핀 3mm | 14 | 알리 링크 (https://ko.aliexpress.com/item/4001011194275.html?gatewayAdapt=glo2kor) |  |  | 30 AWG 실리콘 케이블 (Red) | 1 | _
 |  | 3.5mm 5극 소켓 | 2 | 알리 링크 (https://ko.aliexpress.com/item/32749792104.html?gatewayAdapt=glo2kor) |  |  | 30 AWG 실리콘 케이블 (Black) | 1 | _
 |  | USB-C 단자 SMD | 1 | 링크 (https://www.devicemart.co.kr/goods/view?no=15088068) |  |  | 30 AWG 실리콘 케이블 (Yellow) | 1 | _
 |  | 18650 배터리 단자 - (스프링) | 1 | 알리 링크 (https://ko.aliexpress.com/item/1005001268395173.html?gatewayAdapt=glo2kor) |  |  | 30 AWG 실리콘 케이블 (Blue) | 1 | _
 |  | 18650 배터리 단자 + | 1 | _ |  |  | 30 AWG 실리콘 케이블 (Orange) | 1 | _
 |  | 1.27mm 11핀 굴절 헤더 소켓 | 1 | 링크 (https://www.icbanq.com/P005659127) |  | 스피커 | 헬멧 스피커 모듈 | 1 | 알리 링크 (https://ko.aliexpress.com/item/1005003490852851.html?gatewayAdapt=glo2kor)
 |  | 바디 모듈 핀 보드 | 1 | PI-SIGHT PCB |  | 통화 마이크 | 콘덴서 마이크 | 1 | 알리 링크 (https://ko.aliexpress.com/item/32691068980.html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)
 |  | 1.27mm 11핀 직선 헤더 핀 | 1 | 링크 (https://www.icbanq.com/P005609783) |  |  | 2선 에나멜 케이블 (전원) | 1 | _
 |  | 스프링 D5mm * L10mm | 1 |  |  |  | 3.5mm 4극 잭 | 1 | 알리 링크 - 14mm 4P (https://ko.aliexpress.com/item/32966592930.html?gatewayAdapt=glo2kor)
 |  | M2 볼트 4mm (카메라 케이블 커버) | 2 | 알리 링크 – H 세트 (https://ko.aliexpress.com/item/4000011789077.html?gatewayAdapt=glo2kor) |  | GPS 모듈 | NEO-M8N GPS 모듈 | 1 | 알리 링크 - M8N (https://ko.aliexpress.com/item/1005002579586721.html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)
 |  | M2 볼트 8mm (파이, 이너커버, 마운트) | 9 | _ |  |  | 바디 모듈 핀 보드 | 1 | PI-SIGHT PCB
 |  | LED 보드 | 1 | PI-SIGHT PCB |  |  | 1.27mm 11핀 직선 헤더 핀 | 1 | _
 |  | 1202 SMD LED (Red) | 4 | 전원보드 추출 |  |  | 스프링 D5mm * L10mm | 1 | _
 |  | 30 AWG 실리콘 케이블 (Red) | 2 | 알리 링크 (https://ko.aliexpress.com/item/1005001590476043.html?gatewayAdapt=glo2kor) |  |  | 30 AWG 실리콘 케이블 (Red) | 1 | _
 |  | 30 AWG 실리콘 케이블 (Black) | 2 | _ |  |  | 30 AWG 실리콘 케이블 (Black) | 1 | _
 |  | 30 AWG 실리콘 케이블 (Yellow) | 1 | _ |  |  | 30 AWG 실리콘 케이블 (Yellow) | 1 | _
 |  | 30 AWG 실리콘 케이블 (Blue) | 1 | _ |  |  | 30 AWG 실리콘 케이블 (Blue) | 1 | _
 |  | 30 AWG 실리콘 케이블 (Orange) | 1 | _ |  | 모듈 핀 컨버터 | 1.27mm-2.54mm 핀 컨버터 보드 | 1 | PI-SIGHT PCB
 | 디스플레이 | 프리즘 디스플레이 + AV 컨트롤 보드 Sales 메일 통해서 직접구매 | 1 | OL23C + AV Board (https://www.sz-sonicom.com/productinfo/689881.html) |  |  | 1.27mm 11핀 헤더 소켓 | 1 | 링크 (https://www.icbanq.com/P005659127)
 |  | 5선 에나멜 케이블 | 1 | 알리 링크 - 5core (https://ko.aliexpress.com/item/1005002604413691.html?gatewayAdapt=glo2kor) |  |  | 2.54mm 11핀 헤더 소켓 | 1 | 링크 (https://www.icbanq.com/P005652460)
 |  | 3.5mm 5극 잭 | 1 | _
 |  | M2 볼트 6mm (상단 볼 텐셔너) | 1 | _
 |  | M2 볼트 10mm (하단 볼 텐셔너) | 1 | _
 | 후방카메라 | 카메라 (120도, 30cm 케이블) | 1 | 알리 링크 - 120 Degree (https://ko.aliexpress.com/item/1005003637612356.html?gatewayAdapt=glo2kor)
 |  | M2 볼트 10mm | 2 | _
 | 시스템 마이크 | INMP441 MEMS MIC | 1 | 알리 링크 (https://ko.aliexpress.com/item/1005005933408624.html?scm_id=1007.40050.354490.0&scm-url=1007.40050.354490.0)
 |  | 0805 SMD 저항 10k | 1 | _
 |  | 5선 에나멜 케이블 | 1 | _
 |  | 3.5mm 5극 잭 | 1 | _
 | 무선 리모컨 | ESP WROOM 32 | 1 | 알리 링크 (https://ko.aliexpress.com/item/32899182878.html?gatewayAdapt=glo2kor)
 |  | 리모컨 메인보드 | 1 | PI-SIGHT PCB
 |  | 리모컨 조이스틱 보드 | 1 | PI-SIGHT PCB
 |  | 슬라이드 스위치 | 1 | SK-12D02
 |  | 택트 스위치 | 2 | NW3-A06-B6
 |  | 조이스틱 | 1 | SMD070706
 |  | TP4056 USB-C 5V 전원보드 | 1 | 알리 링크 - 18650 Type-C (https://ko.aliexpress.com/item/1005006310424899.html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)
 |  | USB-C 단자 SMD |  | 전원보드 추출
 |  | 1202 SMD LED (Red) | 1 | 전원보드 추출
 |  | 1202 SMD LED (Blue) | 1 | 전원보드 추출
 |  | 0805 SMD 캐패시터 10uF | 1 | _
 |  | 0805 SMD 캐패시터 100nF | 2 | _
 |  | 0805 SMD 저항 1k5 | 2 | _
 |  | 0805 SMD 저항 1k2 | 1 | _
 |  | 0805 SMD 저항 1k | 1 | _
 |  | HX4002B 3.3V 전원보드 | 1 | 알리 링크 (https://ko.aliexpress.com/item/1005004680099594.html?gatewayAdapt=glo2kor)
 |  | 18650 배터리 단자 - (스프링) | 2 | _
 |  | 2선 에나멜 케이블 (전원) | 1 | 알리 링크 - 2core (https://ko.aliexpress.com/item/1005002604413691.html)
 |  | 스프링 D5mm * L10mm | 1
 |  | M3 볼트 12mm | 1 | 알리 링크 - 12mm (https://ko.aliexpress.com/item/1005005742172855.html?scm_id=1007.40050.354490.0&scm-url=1007.40050.354490.0)
 |  | M3 와셔 | 1 | _
 |  | M3 너트 | 1 | _
 |  | M2 볼트 4mm (리모컨 pcb) | 2 | _
 |  | M2 볼트 10mm (리모컨 힌지) | 1 | _
 |  | M2 볼트 8mm (배터리커버 힌지) | 1 | _
 |  | M2 너트 | 1 | 알리 링크 - M2 (https://ko.aliexpress.com/item/1005004833515587.html)

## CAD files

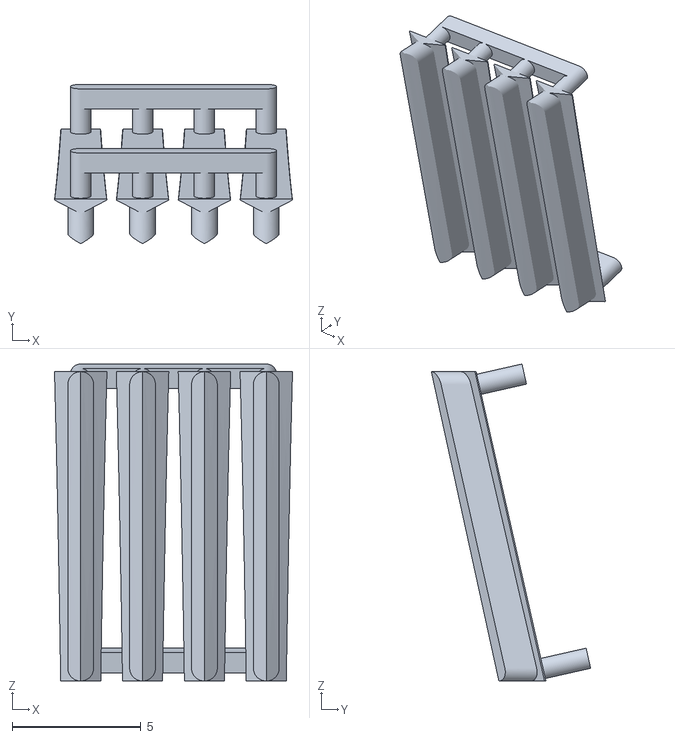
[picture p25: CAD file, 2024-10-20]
CAD_files/3D_Print_order/TRANSPARENT_RESIN-body_light_slit.stl
9.24 x 6.18 x 12.3

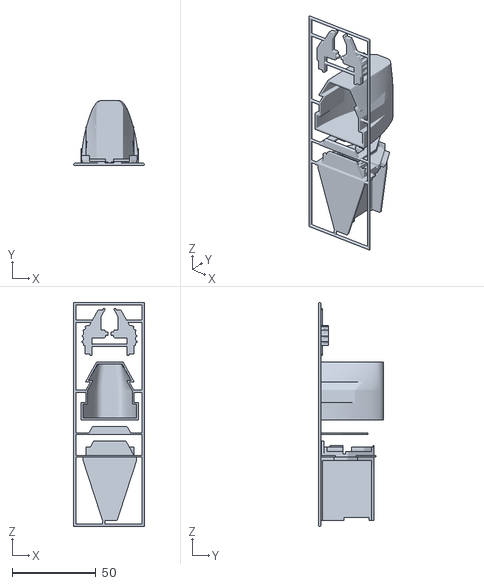
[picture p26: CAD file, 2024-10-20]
CAD_files/3D_Print_order/SLS-GPSmodule.stl
42.2 x 39.0 x 133.7

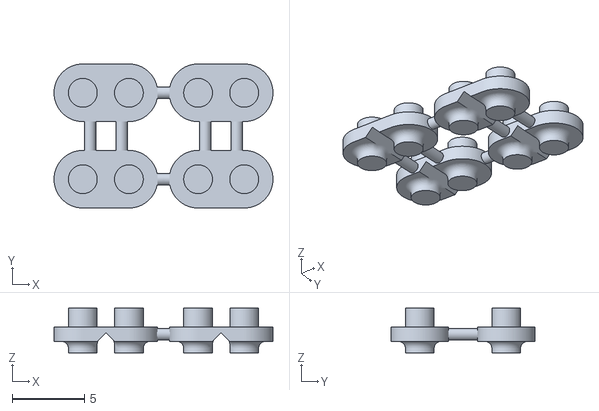
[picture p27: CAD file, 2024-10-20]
CAD_files/3D_Print_order/TRANSPARENT_RESIN-remote_light_hole.stl
15.2 x 10.0 x 3.10

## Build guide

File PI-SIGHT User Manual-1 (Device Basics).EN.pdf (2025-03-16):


# PI-SIGHT Device User Manual

www.vudev.net | VUDEV | PI-SIGHT

Notes · · · · · · · · · · · · · · · · · · · · · · · · · · · · · · · · · · · · · · · · · · · · · · · · · · · · · · · · · · · · · · 3 1 Introduction/Product Composition · · · · · · · · · · · · · · · · · · · · · · · · · · · · · · · · · · 4
2 Technical specifications · · · · · · · · · · · · · · · · · · · · · · · · · · · · · · · · · · · · · · · · · · 5

### 3 Getting Started

3.1 PI-SIGHT Part Names · · · · · · · · · · · · · · · · · · · · · · · · · · · · · · · · · · · · · · · · · · · · · 6 3.2 Installing the body set · · · · · · · · · · · · · · · · · · · · · · · · · · · · · · · · · · · · · · · · · · · · 8 3.3 Installing the remote control · · · · · · · · · · · · · · · · · · · · · · · · · · · · · · · · · · · 11 3.4 Inserting the battery and memory card · · · · · · · · · · · · · · · · · · · · · · · · · · · · · 12 3.5 Power on and off, charging · · · · · · · · · · · · · · · · · · · · · · · · · · · · · · · · · · · · · · · 13 4 Software Installation · · · · · · · · · · · · · · · · · · · · · · · · · · · · · · · · · · · · · · · · · · · · · · · · · · · · · 19 5 Troubleshooting · · · · · · · · · · · · · · · · · · · · · · · · · · · · · · · · · · · · · · · · · · · · · · · · · · · · · · · · · 20

### 5.1 Main body operation problem 5.2 Remote control charging light problem 5.3 Display fixation issue

Index | VUDEV | PI-SIGHT

Please observe the following precautions:

- Observe all regulations regarding camera use.
- The camera generates a low-level magnetic field. Keep it away from medical equipment to avoid interference.
- The low-level magnetic field generated by the camera can cause interference with other electronic devices.
- Careless use can be dangerous and can result in serious injury. Be sure to follow the safety precautions in the document.
- Turn off the product in areas where wireless communication is prohibited.
- Check again that the product is properly secured before use. If the product is detached during use, it may be damaged and cause an accident.
- If you notice any unusual smell, heat, or other abnormal symptoms while using or charging the product, immediately stop charging or using it.
- If the product is attached to a helmet, the helmet warranty may be voided or the helmet may be interfered with. Therefore, you should fully understand the risks of accidents caused by this before using the product.
- Before using the product, make sure you understand the laws in your area and comply with the relevant regulations.
- Do not hit the product with sharp tools or pull the cable excessively. This may damage the product.
Notes | VUDEV | PI-SIGHT
- Keep out of reach of pets and infants.
- Check in advance that the camera is operating normally.
- Do not use under direct sunlight for long periods of time. The product may be damaged and may cause burns due to overheating.
- Do not use or store the product with the battery installed inside a car in hot weather. The battery may overheat or catch fire.
- Do not install a physically damaged battery. This may cause an explosion or accident.
- Battery life may vary depending on the situation, environment, and function.
- Store the product at room temperature. The device may be damaged if placed in extremely low or high temperatures.
- Be careful to protect the display, and if foreign substances adhere to the prism, wipe the surface with a soft cloth.
- Do not use the product in rainy or snowy environments as the product is not waterproof.
- This device is a business (Class A) electromagnetic compatibility device, so sellers or users should be aware of this, and it is intended for use in areas other than the home.

Thank you for purchasing PI-SIGHT.

PI-SIGHT is a head-up display (HUD) device that displays necessary information in front of the helmet wearer's eyes.
You can check the necessary information without moving your head through the translucent display in front of your eyes, and you can operate the device with a wireless remote control.

It operates based on the Raspberry Pi Zero 2W board and Raspberry Pi OS, and you can download and install the desired software on the memory card or develop it yourself.
You can also connect external modules such as a Bluetooth headset or GPS, so you can use it for various purposes such as navigation, racing instrumentation, and aviation instrumentation boards as needed.

This manual covers the rearview software that is provided by default. You need a separate Windows PC to check the video recorded on the device.

For more information about modules and software that can be used with PI-SIGHT, please refer to vudev.net.

1. Introduction / Product Composition | VUDEV | PI-SIGHT

The box contains the following items:

- PI-SIGHT display unit
- PI-SIGHT main body-camera unit
- PI-SIGHT PI microphone unit
- PI-SIGHT remote control
- Micro SD memory (for rearview software installation)
- Helmet mount
- Velcro for microphone attachment
- Phillips screwdriver
- User manual
*The product does not include a battery or charger. You must purchase them separately to operate and charge the product. For more information, please refer to the technical specifications.
*The product does not include an adapter to connect the Micro SD memory to a PC. You must purchase them separately to check recorded videos and reinstall the software.

*Batteries must be purchased separately
2. Technical specifications | VUDEV | PI-SIGHT

PI-SIGHT Body Set

- Length: Main body 105.5mm / Camera 21mm / Display 71mm
- Height: Main body 35mm / Camera 23.5mm / Display 47.5mm
- Width: Main body 34.4mm / Camera 35mm / Display 38mm
- Weight: 145g (including battery)
- Screen size: 0.23 inches / 3 meters 50 inches
- Screen resolution: 640*400
- Camera: 5 million pixels 120 degree wide angle
- Video resolution: 1296*860p (user changeable / up to 1920*1080p)
- Motherboard: Raspberry Pi Zero 2W
- Processor: 1GHz quad-core 64-bit Arm Cortex-A53 CPU
- RAM capacity: 512MB
- Wireless communication: 2.4GHz 802.11 b/g/n Wi Fi, Bluetooth 4.2, BLE
- Connector: USB-C for charging, 3.5mm for display, 3.5mm for Pi microphone
- Memory card: 32GB Micro SD (Class 10 or higher recommended for additional purchase)
- *Battery: 18650 Li-ion replaceable

PI-SIGHT remote control

- Length: 87mm
- Height: 87.5mm
- Width: 23mm
- Weight: 85g (including battery)
- Connector: USB-C for charging
- Wireless communication: Bluetooth 4.2
- *Battery: 18650 Li-ion replaceable
*Batteries must be purchased separately
- Operating time: Main body about 5 hours, remote control about 16 hours
(3500mAh, based on medium screen brightness, may vary depending on software used)

3. Getting Started – PI-SIGHT Part Names | VUDEV | PI-SIGHT

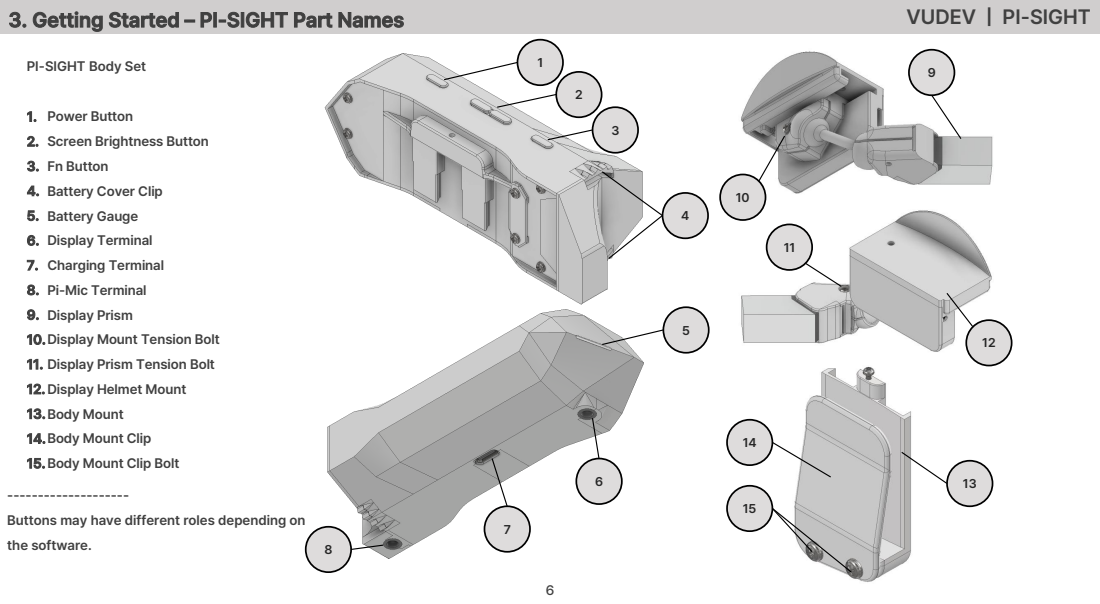
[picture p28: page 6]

PI-SIGHT Body Set

1. Power Button
2. Screen Brightness Button
3. Fn Button
4. Battery Cover Clip
5. Battery Gauge
6. Display Terminal
7. Charging Terminal
8. Pi-Mic Terminal
9. Display Prism
10.Display Mount Tension Bolt
11. Display Prism Tension Bolt
12.Display Helmet Mount
13.Body Mount
14.Body Mount Clip
15.Body Mount Clip Bolt
Buttons may have different roles depending on
the software.

3. Getting Started – PI-SIGHT Part Names | VUDEV | PI-SIGHT

Buttons may have different roles depending on the software.

PI-SIGHT remote control

### 16. Camera helmet mount 17. Camera tension bolt 18. Camera lens 19. Power switch 20. Charging LED

21. 5-way joystick button (up, down, left, right, press)

### 22. Thumb button 23. Battery cover 24. Charging terminal 25. Index button 26. Fixing bolt

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
16 17

18

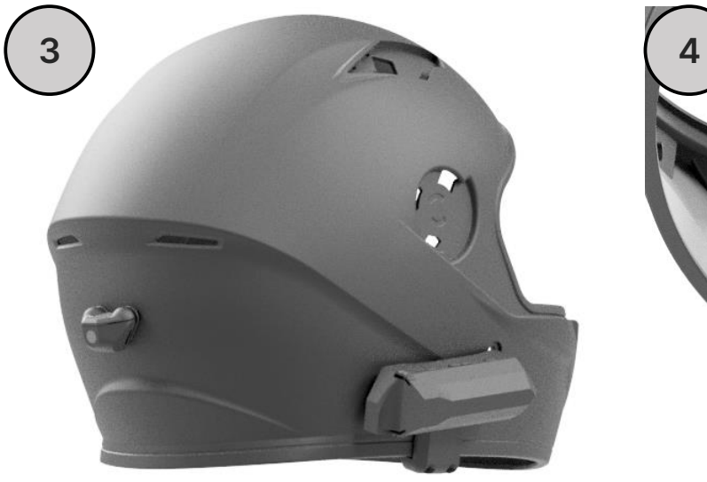
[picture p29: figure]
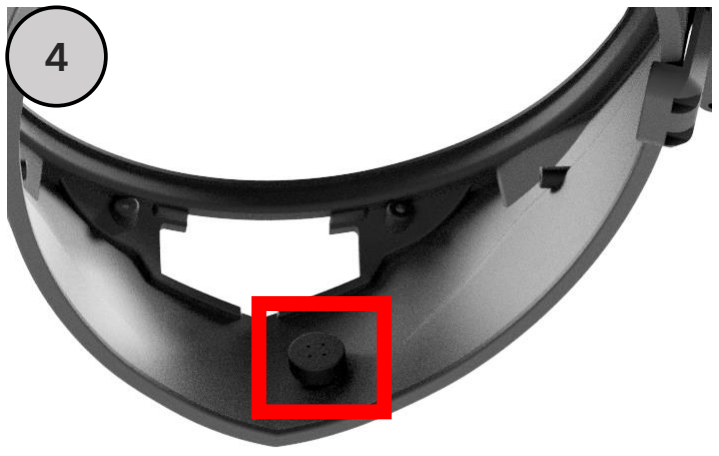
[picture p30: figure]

Caution!
Before bonding the parts, clean the helmet surface of any foreign matter and dry it completely. Attach the body so that the camera cable is not pulled excessively.

## VUDEV | PI-SIGHT

## 3. Getting Started – Installing the Body Set

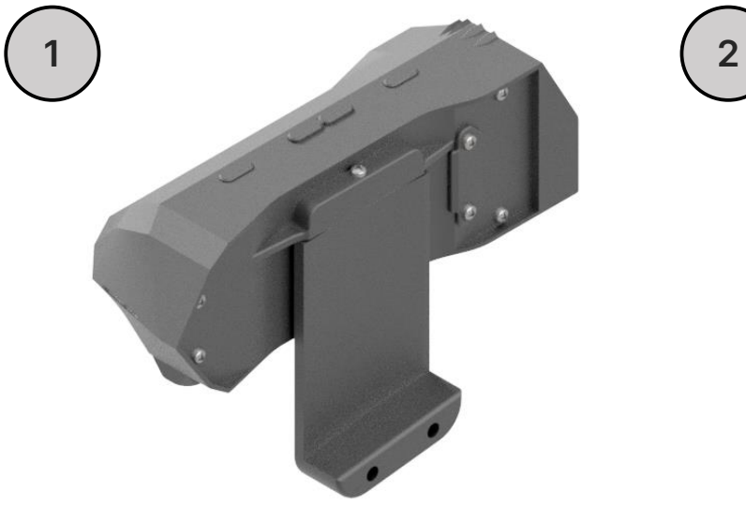
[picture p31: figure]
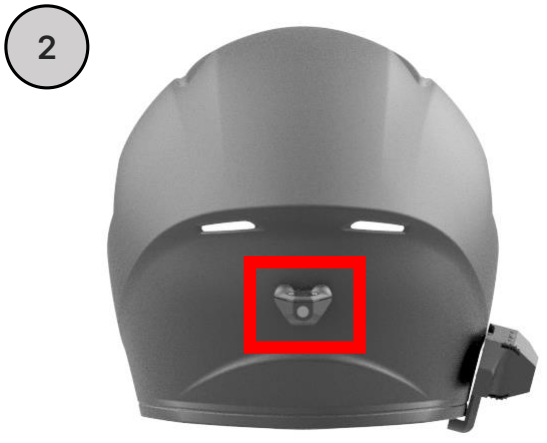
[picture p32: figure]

### 1. Remove all bolts and body mount clips of the body

mount, and attach it to the main body.

### 2. Slightly loosen the camera tension bolts to allow the

camera helmet mount to move, and attach the camera so that it is positioned in the center of the left and right sides of the helmet according to the curve of the helmet.

### 3. Attach the body mount to the helmet according to the

length of the camera cable.

### 4. Attach the pi microphone to the front of the mouth

inside the helmet.

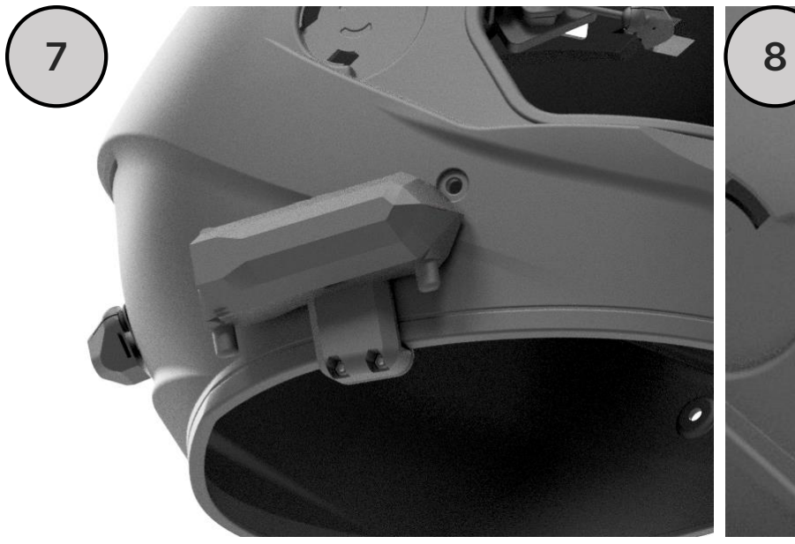
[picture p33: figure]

Caution!
Be careful not to pull too hard when organizing cables. After connecting cables, organize excess wires behind the inner padding to avoid damaging the wiring.

## 3. Getting Started – Installing the Body Set

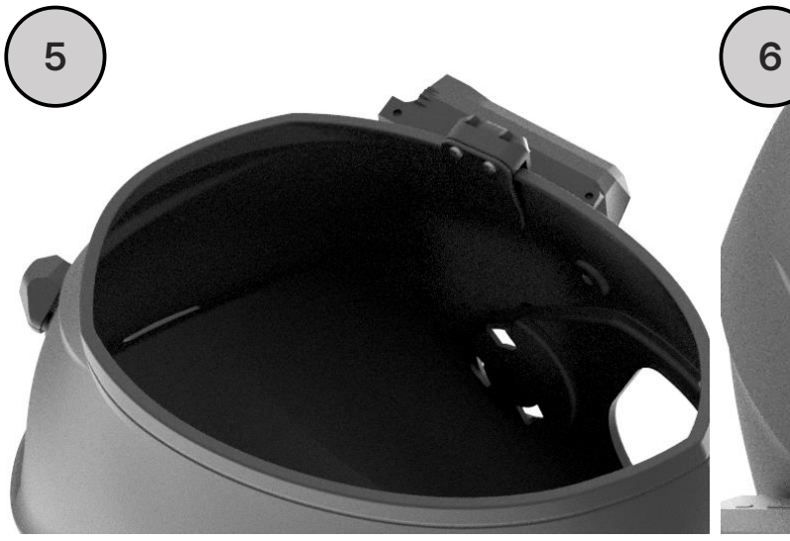
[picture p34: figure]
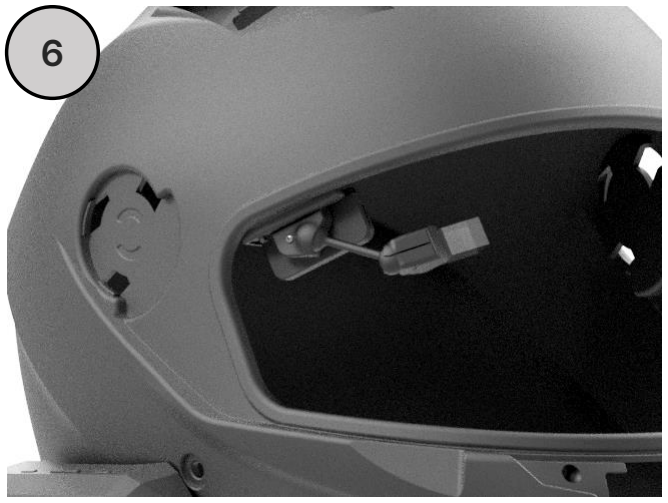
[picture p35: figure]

### 5. Route the Pi mic cable inside the outer shell of the helmet

and attach the body mount clip and bolt.

6. Attach the display helmet mount to the helmet.

### 7. Route the display cable inside the outer shell of the

helmet and attach it to the main body.

### 8. Adjust the display mount and prism tension bolts so that

they can be moved by hand but do not move while riding. Then, attach the helmet and check that it is properly in your field of vision.

## 3. Getting Started – Installing the Body Set

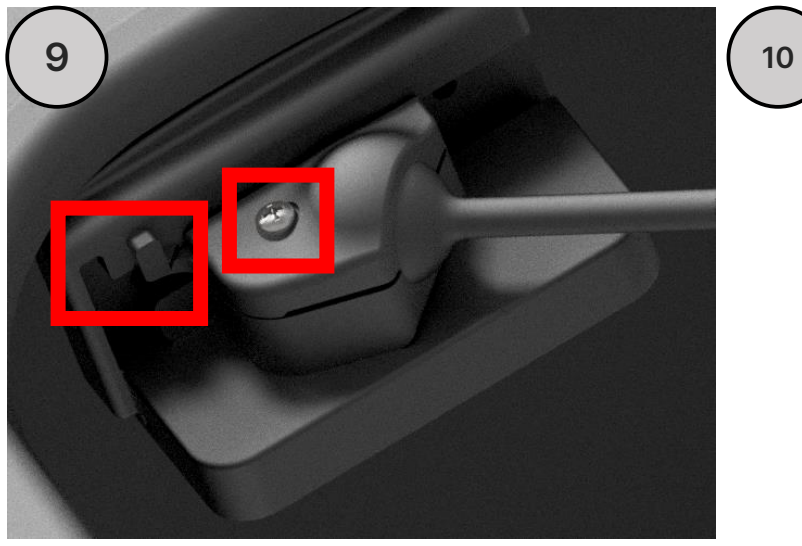
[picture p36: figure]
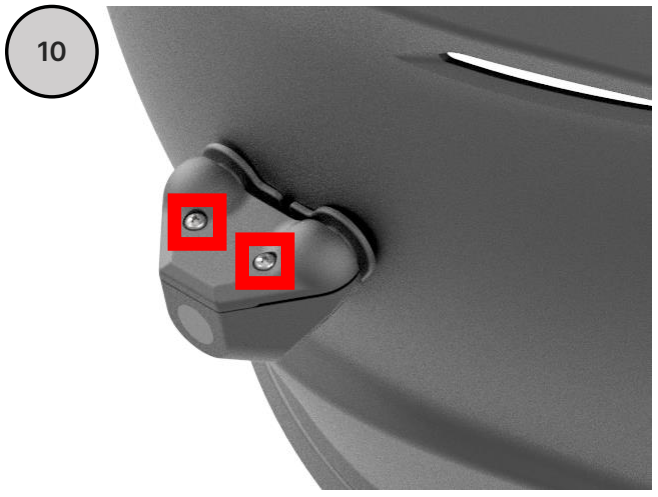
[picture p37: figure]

### 9. Fully loosen the display mount tension bolt and remove

the cover, and you can adjust the mount forward and backward by moving the clip.

10.Turn on the power and check the rear camera to adjust the camera's up and down angle, and tighten the camera tension bolt to prevent it from moving.

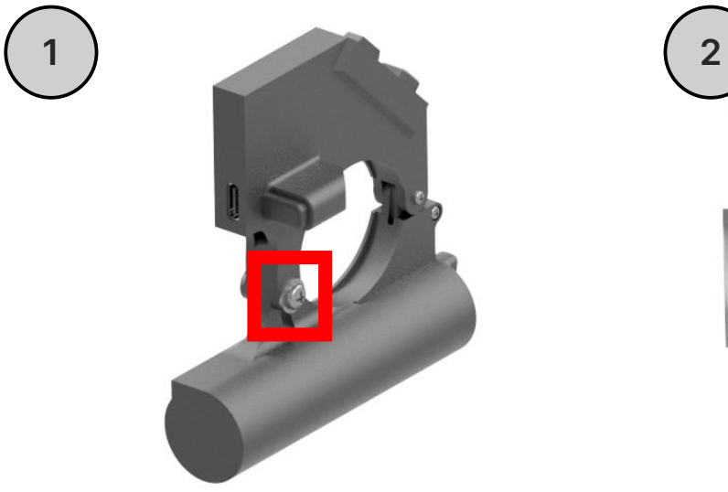
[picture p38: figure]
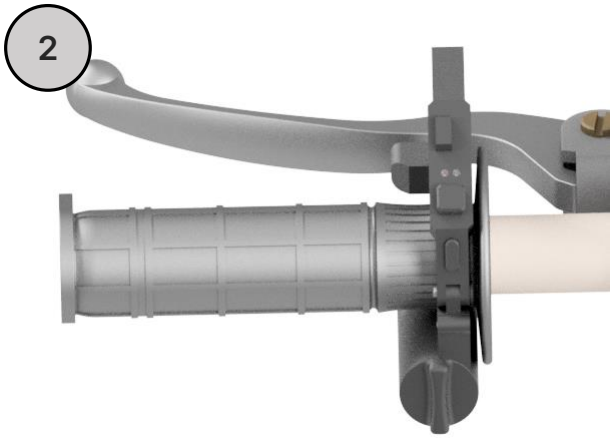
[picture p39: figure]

### 1. Loosen the remote control fixing bolts so that the top

and bottom of the remote control can move.

2. Mount the remote control on the left handlebar.

### 3. Make sure that the thin connection part of the remote

control faces the lever so that it does not interfere with the movement of the lever.
After that, hold the top and bottom of the remote control so that it does not move, and tighten the fixing bolts so that it does not come loose.
Caution!
Tightening the remote control/top/bottom part too much to the handlebar may damage the hinge. Depending on the bike, this may interfere with the movement of the lever.

## 3. Getting Started – Installing the Remote Control

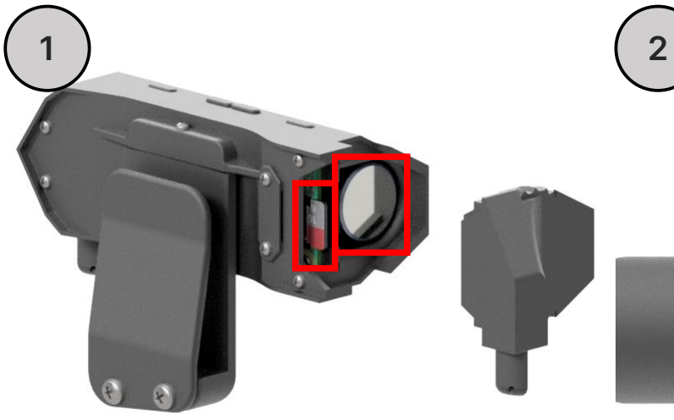
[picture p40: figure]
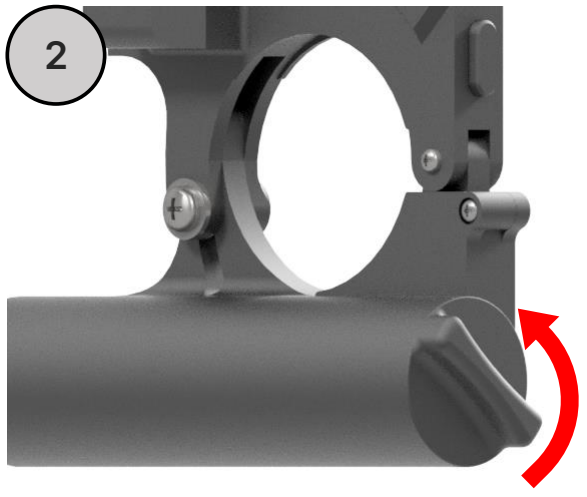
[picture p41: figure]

### 1. Pinch the upper/lower clips of the main body battery

cover and pull to separate the cover.
Insert the battery with the + side facing inward, insert the memory card into the slot with the top side facing inward, and close the battery cover.

### 2. Turn the handle of the remote control battery cover 45

degrees counterclockwise.

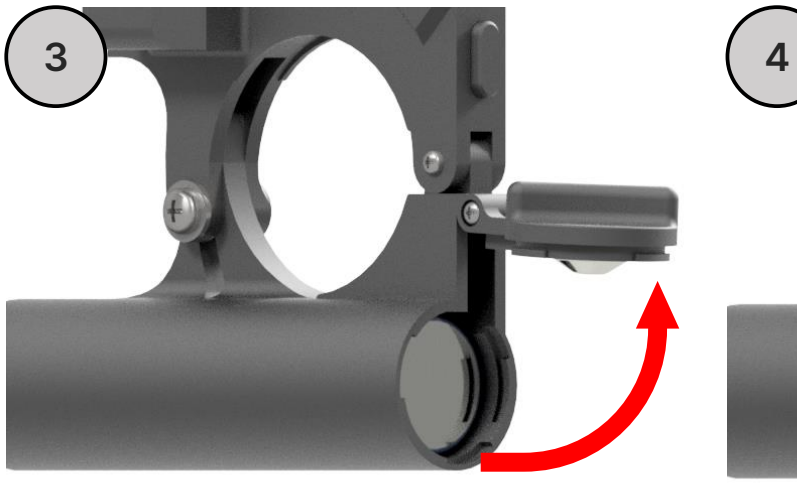
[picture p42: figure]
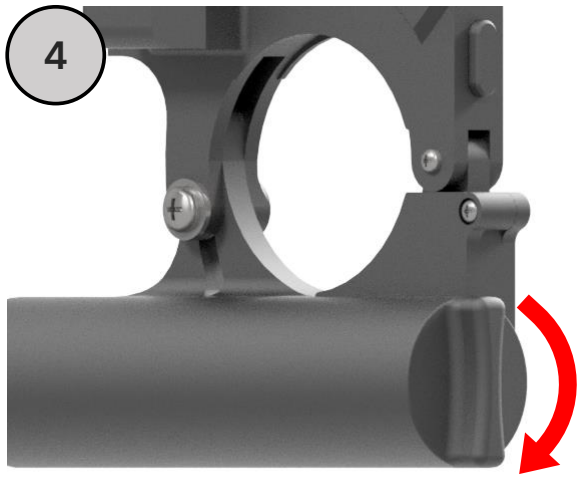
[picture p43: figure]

### 3. Open the remote control battery cover and insert the

battery with the + side facing inward.

### 4. Close the battery cover and turn the handle clockwise

so that it is aligned up and down until you feel a click.

Caution!
Always insert the battery with the + side facing inward. Make sure the internal module pins are engaged when attaching the main body battery cover.

## 3. Getting started – Inserting the battery and memory card

## 3. Getting started – Powering on and off, charging

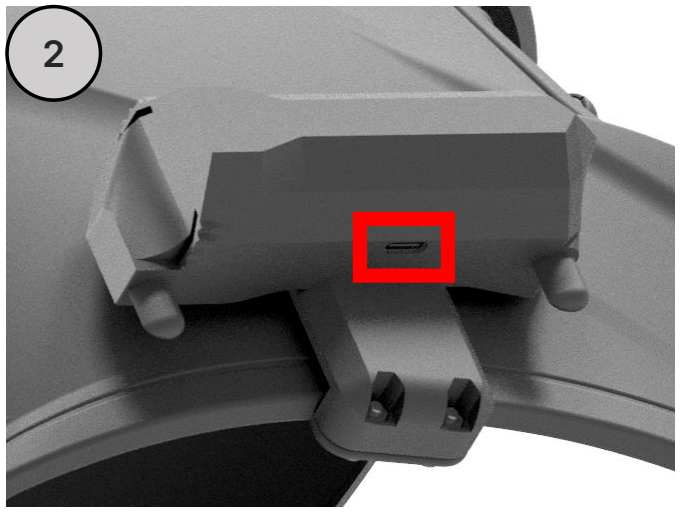
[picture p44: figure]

### 1. Press the power button on the main body once to turn it on, and

press it twice in a row to turn it off. The remaining battery level is
indicated by four red lights on the battery gauge.
(100%/75%/50%/25%, low power blinking)

### 2. You can charge the battery installed in the main body through the

USB-C terminal at the bottom of the main body. The power remains on while charging and cannot be turned off.

### 3. When you push the power switch on the remote control up, the

power turns on, and when you push it down, the power turns off.

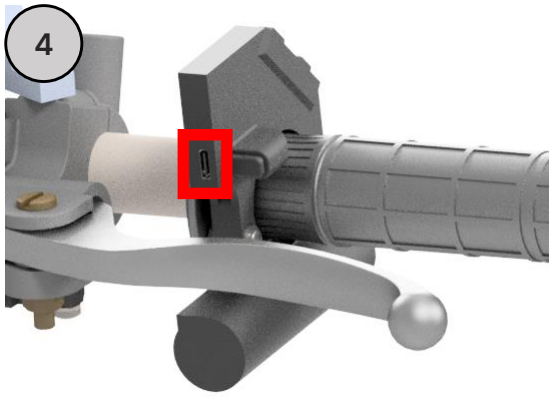
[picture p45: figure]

### 4. You can charge the battery installed in the remote control via the

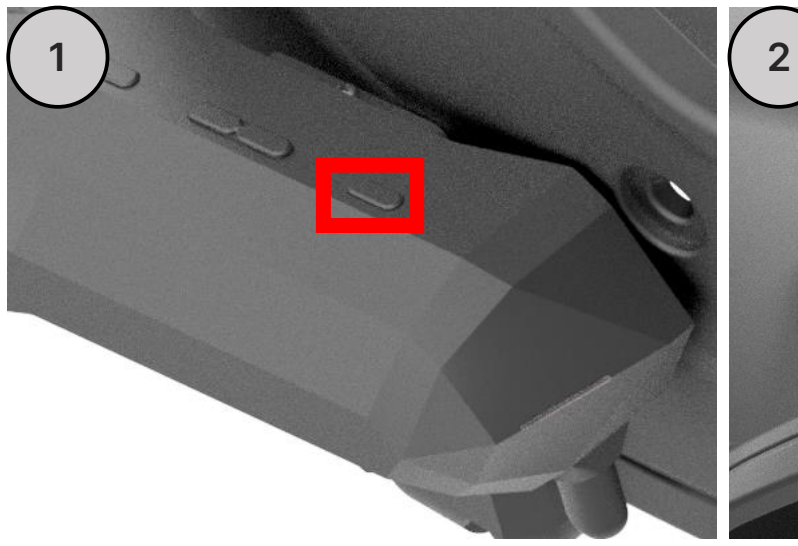
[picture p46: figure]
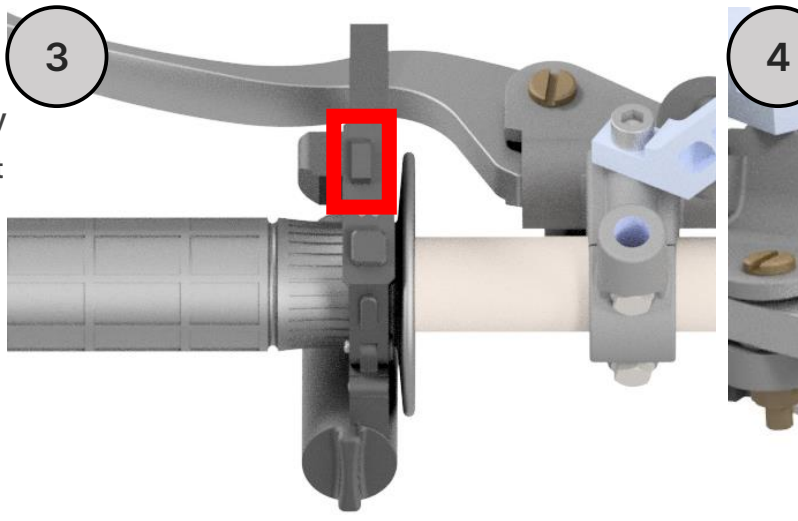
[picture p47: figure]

USB-C terminal on the back of the remote control. When the battery is charging, the red LED lights up, and when it is on standby without a battery or when charging is complete, the blue LED lights up.

If you connect the bike's USB charging terminal to the remote control, it can act as a charging station that swaps the main body and battery after charging, allowing you to use the device even during long rides.
Since there is no indication that the remote control is powered on, make sure to turn the power off after use to prevent battery discharge.

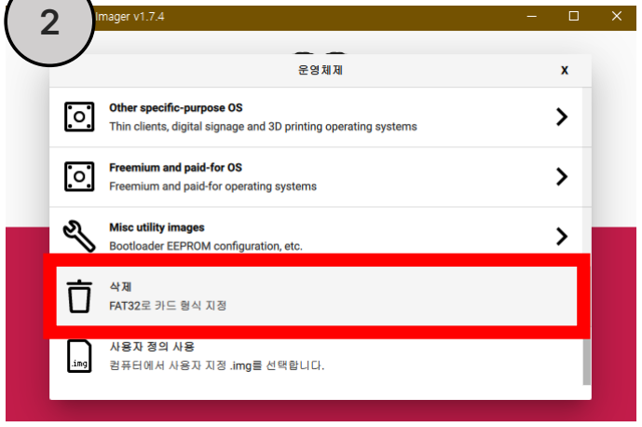
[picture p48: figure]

1 2

### 1. Download the Raspberry Pi Imager program appropriate

for your PC operating system from www.raspberrypi.com, install it, and then run it.

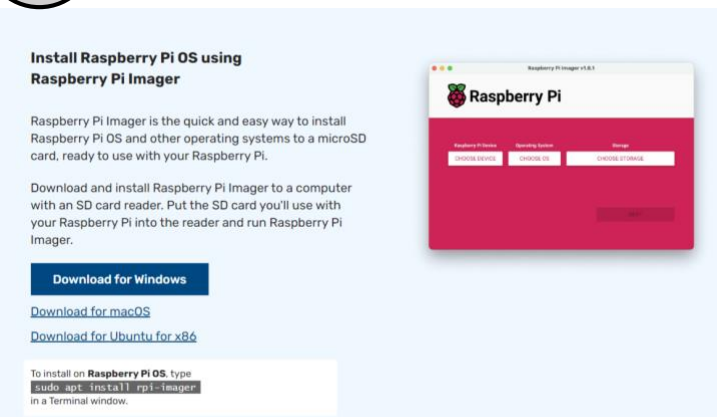
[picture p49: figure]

### 2. Connect the memory card, select Erase on the Operating

System tab, click on the memory card on the Storage tab, and then click Write to format the memory card.

### 3. Download the img file of the desired software from

vudev.net, click Use Custom in the Operating System tab of the Raspberry Pi Imager, and select the downloaded img file.

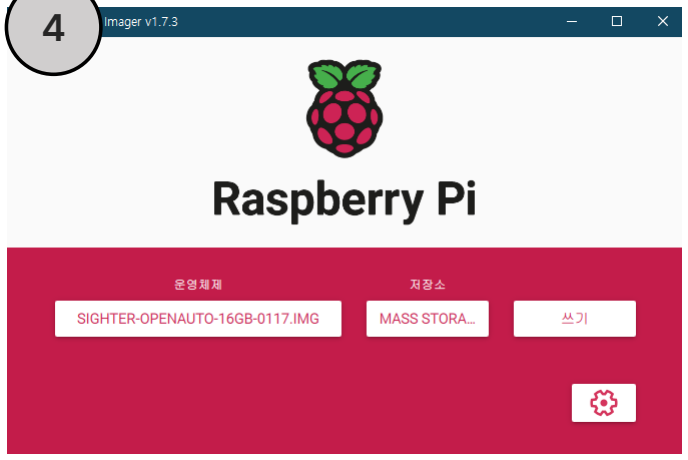
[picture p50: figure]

### 4. Select the memory card in the Storage tab, then click

Write to begin installing the software on the memory card. Once the installation is complete, insert it into your device and use it.
Memory card format errors may occur when removing the memory card during a write operation or when exiting the program. This can be resolved using methods such as diskpart.

## 4. Software Installation

5.2 Remote control charging light problem
- When the remote control is turned on and the battery is fully charged, the red and blue lights may turn on simultaneously or alternately, but this is normal operation.
5.3 Display Fixation Issues
- If the display is not firmly fixed and moves easily, adjust the tension
bolts on the display mount and prism to adjust the fixation strength.
5. Troubleshooting | VUDEV | PI-SIGHT

5.1 Main body operation problem
- If the battery gauge light comes on but the display does not work, check the connection between the main body and the display terminal.
- If the battery gauge light comes on but the boot screen does not appear, check if the memory card is inserted properly.
- If the battery gauge light does not come on, check if the battery is inserted properly.
- If the device continuously saves/deletes images and the memory card reaches its lifespan after a certain period of time, the device may not work properly. In this case, replace the memory card and reinstall the software.

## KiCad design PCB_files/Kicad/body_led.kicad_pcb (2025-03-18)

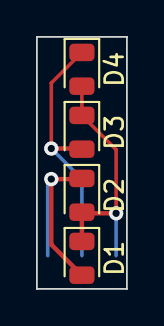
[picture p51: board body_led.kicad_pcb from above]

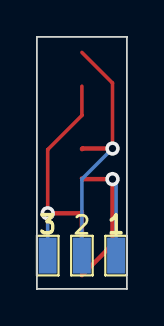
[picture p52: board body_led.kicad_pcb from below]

Board: 2 copper layers, 5.0 x 14.0 mm, 7 parts (3 on the bottom side), 3 nets.

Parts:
D1: 25%; LED_0805_2012Metric
D2: 50%; LED_0805_2012Metric
D3: 75%; LED_0805_2012Metric
D4: 100%; LED_0805_2012Metric
TP1: 1; TestPoint_1.0x2.0mm
TP2: 2; TestPoint_1.0x2.0mm
TP3: 3; TestPoint_1.0x2.0mm

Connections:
unnamed: D1.2 (A), D2.1 (K), TP1.1
unnamed: D1.1 (K), D2.2 (A), D3.1 (K), D4.2 (A), TP3.3
unnamed: D3.2 (A), D4.1 (K), TP2.2

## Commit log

2025-03-16 Rename PI-SIGHT 사용설명서-1 (디바이스 기본).EN.pdf to PI-SIGHT User Manual-1 (Device Basics).EN.pdf
2025-03-18 Add Kicad Project
    [body.kicad_pcb, body.kicad_sch, body_led.kicad_pcb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]
